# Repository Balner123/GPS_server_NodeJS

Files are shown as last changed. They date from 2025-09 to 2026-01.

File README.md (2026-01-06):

## LOTR - Location Tracker system

Dokumentace (PDF): [Dokumentace_LOTR_system](https://github.com/Balner123/GPS_server_NodeJS/blob/main/docs%26LaTex/FINAL_latex/Balner_LOTR_system.pdf)

Demo Serveru (Oracle cloud): [lotr-system.xyz](https://lotr-system.xyz)

Demo Prezentačního videa : [lotrsystem2026](https://www.youtube.com/@Lotrsystem)

## Popis a cíl projektu (deprecated)

Projekt LOTR (Location Tracker) je systém pro GPS sledování, který zahrnuje vlastní hardware, backendový server s webovým rozhraním, a APK pro Android (možná i jiné OS). 

### Klíčové Funkce (deprecated)

*   **Hardware:** Nízkoenergetické zařízení postavené na desce LilyGO T-Call (ESP32 + A7670E SIM modul), které v periodických intervalech zjišťuje polohu a odesílá ji na server dle konfigurace.
*   **Server:** Backend v Node.js (Express), který přijímá data, ukládá je do MySQL databáze a poskytuje API pro webové rozhraní.
*   **Webové rozhraní:** Umožňuje vizualizaci aktuální i historické polohy zařízení na mapě a konfiguraci jeho chování. nastavení dohledu (omezení plochy s výstrahou poopupuštění etc.), uživatelské učty + administrativní vhled do DB
*   **Aplikace** funkce stejného rázu jako HW zařízení + funkce "Dohledu" , "zamknutí" + "runaway report"

### Funkce HW

*   **registrace zařízení:** v servisním (OTA) režimu pomocí WiFi a webového serveru běžícího přímo na zařízení se uživatel přihlásí k registrovánému účtu a tím se bezpečně spáruje.
*   **odesílání dat:** Zařízení podporuje více režimů odesílání, které lze konfigurovat:
    1.  **Simple Mode:** Zjištění polohy a okamžité odeslání.
    2.  **Batch Mode:** Zařízení nejprve nasbírá určený počet poloh do interní paměti (cachování) a poté je odešle najednou v dávce. Tento režim výrazně šetří baterii snížením počtu síťových připojení.
*   **Odolnost vůči výpadkům:** Díky cachování zařízení neztratí data, pokud dočasně ztratí připojení k síti. Všechny nasbírané body odešle, jakmile je připojení opět dostupné.
*   **další funkce budou přidáné průběžně**

## Technologie a Hardware

### Software
Node.JS -> vybrán pro asynchronost a znalost
  + express -> minimalistiký
  + jakékoliv moduly
Možnost jakýchkoliv frontend frameworků

### Hardware

[lilygo t-call v1.0 A7670E](https://github.com/Balner123/GPS_server_NodeJS/blob/LilyGO-T-A76XX-main/MAIN/gps_tracker.ino)

[Multi-GNSS polohovací modul – L76K – GPS, BeiDou (BDS), GLONASS, QZSS – Waveshare 23721](https://botland.cz/gps-moduly/22732-multi-gnss-polohovaci-modul-l76k-gps-beidou-bds-glonass-qzss-waveshare-23721.html)

[Li-ion cell charger TP4056 with microUSB protection and STEP-UP booster ](https://www.laskakit.cz/nabijecka-li-ion-clanku-tp4056-boost-mt3608/)

[GeB Li-Ion Battery 1x18650 1S1P 3.7V 3200mAh  | LaskaKit](https://www.laskakit.cz/en/geb-li-ion-baterie-1x18650-1s1p-3-7v-3200mah/)

+ knihovny 

## Postup a vývoj+ milníky (deprecated)

- definování cílů -> základem byl fyzický Tracker -> server minimáně
- přechod na t-cal v1.4  místo v1.0 (lepší SIM modul + zkratování původní desky)
- větší zaměření na serverovou část

- více v "Poznámky k vývoji projektu.pdf" (neaktualizované z data 20.8)
- PLANY.txt
- a jakekoliv readme v podadresářích součástí projektu (analyzy dělané LLM - hlavně gemini)
- zbylá dokumentace je vedená v "Obsidian" bude exportována průběžně

## Další součásti (deprecated)
APK -> pro android a její vyvěšení na Google play (?) --> fee 20 dollars --> discontinued
3D tisknutá schránka pro hardwerovou část (?) --> stability issues --> ?

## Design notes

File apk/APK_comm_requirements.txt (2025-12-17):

===================================
APK Communication Requirements
===================================

1) Identita a autentizace
-------------------------
- APK klient používá uživatelský účet. Přihlášení probíhá přes `POST /api/apk/login` s JSON payloadem:
  {
    "identifier": "username nebo email",
    "password": "Secret123!",
    "installationId": "apk-install-uuid-12345"
  }
- Při úspěchu server založí HTTP session (`connect.sid` cookie) a vrací:
  {
    "success": true,
    "device_is_registered": false
  }
- Pokud účet není ověřen, server vrátí `403` a hlášku `Account not verified...`.
- Chybějící pole ⇒ `400`, špatné přihlašovací údaje ⇒ `401`, neexistující uživatel ⇒ `401`.
- Logout provádí `POST /api/apk/logout` (session zanikne, cookie se smaže).

2) Registrace zařízení / instalace APK
--------------------------------------
- Každá instalace APK vystupuje jako zařízení s `device_id = installationId` a `device_type = APK`.
- Varianty registrace:
  a) Legacy endpoint `POST /api/apk/register-device` (vyžaduje aktivní session z kroku 1).
     Payload:
     {
       "installationId": "apk-install-uuid-12345",
       "deviceName": "Pixel 8 Pro"
     }
     Odezvy: `201` vytvořeno, `200` již registrováno, `409` konflikt (patří jinému uživateli), `401` bez session, `400` chybějící pole.
  b) Unified endpoint `POST /api/devices/register`:
     {
       "client_type": "APK",
       "device_id": "apk-install-uuid-12345",
       "name": "Pixel 8 Pro"
     }
     Vyžaduje platnou session. Stejné návratové kódy jako výše.
- Server ukládá zařízení do `devices` a přidělí jej aktuálně přihlášenému uživateli.

3) Handshake (konfigurace + instrukce)
--------------------------------------
- Endpoint: `POST /api/devices/handshake`.
- Request (odesílat po startu aplikace a periodicky):
  {
    "client_type": "APK",
    "device_id": "apk-install-uuid-12345",
    "power_status": "ON",
  }
- Server kroky:
  • Pokud zařízení není registrováno ⇒ `registered=false` (HTTP 200). Aplikace má zařízení znovu zaregistrovat a pozastavit upload dat.
  • Aktualizuje `device_type`, `power_status`, `last_seen`. Pokud `power_status` potvrzuje předchozí instrukci, nastaví `power_instruction='NONE'`.
- Response při registrovaném zařízení:
  {
    "registered": true,
    "config": {
      "interval_gps": 15,
      "interval_send": 1,
      "satellites": 7,
      "mode": "batch"
    },
    "power_instruction": "NONE" | "TURN_OFF"
  }
- Aplikace musí respektovat dodanou konfiguraci a připravit se na instrukce vypnutí.

4) Odesílání telemetrie + potvrzení
-----------------------------------
- Endpoint: `POST /api/devices/input` (sdílený s HW). Middleware `authenticateDevice` ověřuje `device`/`device_id` proti DB – session není nutná, klíčem je registrované zařízení.
- Payload může být jeden objekt nebo pole objektů; každý bod musí mít `device`, `latitude`, `longitude`:
  {
    "device": "apk-install-uuid-12345",
    "client_type": "APK",
    "latitude": 50.12345,
    "longitude": 14.45678,
    "speed": 36.2,
    "accuracy": 5.1,
    "satellites": 12,
    "timestamp": "2025-12-01T10:15:00Z",
    "power_status": "OFF"   // pokud došlo k vypnutí po instrukci
  }
- Batch varianta:
  [ { ... }, { ... } ] – server uloží všechny body atomicky; prázdné pole ⇒ `400`.
- Po uložení server zaktualizuje `last_seen`, případně převezme nový `power_status`. Pokud status splní instrukci `TURN_OFF`, instruktáž se v DB vynuluje.
- Úspěšná odpověď: `{ "success": true }` (`200`).
- Chyby:
  • `400` – chybí `device`, `latitude`, `longitude` nebo některý bod je nekorektní.
  • `404` – `device` není registrováno.
  • `500` – interní chyba (klient opakuje s backoffem, nemazat uložená data).

5) Power status & instrukce
---------------------------
- `power_status`: `ON` | `OFF` (lze rozšířit o `LOW_POWER`, `FAULT`, ale APK aktuálně posílá pouze ON/OFF).
- `power_instruction`: `NONE` | `TURN_OFF` (nastavuje uživatel z UI přes `/api/devices/power-instruction`).
- Acknowledgement probíhá implicitně:
  • APK při dalším handshake nebo uploadu odešle `"power_status":"OFF"`.
  • Server při shodě `power_instruction=TURN_OFF` a `power_status=OFF` instrukci zruší.
- Aplikace musí zachovat konzistenci stavu: pokud obdrží `TURN_OFF`, přejde do OFF režimu, lokálně uloží data a potvrdí stav při nejbližším requestu.

6) Chování při chybách
----------------------
- `POST /api/apk/login`: 400 (missing fields), 401 (invalid credentials/user not found), 403 (account not verified), 500 (internal).
- `POST /api/devices/register`: 200/201 success, 400 invalid payload, 401 missing session, 409 conflict, 500 internal.
- `POST /api/devices/handshake`: 200 + `registered=false` (není registrováno), 500 internal error.
- `POST /api/devices/input`: 200 success, 400 invalid payload, 404 device unknown, 500 internal error.
- Po obdržení 401/403 musí APK uživatele znovu přihlásit (session je neplatná) a požadavek neopakovat se stejnou cookie.
- Při 409 (konflikt zařízení) je nutné uživateli nabídnout volbu změnit účet nebo zařízení přeregistrovat ručně.

7) Síťové požadavky & retry logika
----------------------------------
- Komunikace probíhá výhradně přes HTTPS. Session cookie `connect.sid` musí být bezpečně uložena (HttpOnly, Secure) a přikládaná k routám, které vyžadují autentizaci uživatele (`/api/apk/*`, `/api/devices/register`).
- Doporučený timeout požadavků < 10 s. Při selhání používat exponenciální backoff (start 5 s, max 60 s) a zachovat lokální buffer poloh.
- Telemetrii cacheovat offline; frontu odeslat v původním pořadí, protože server ukládá timestampy tak, jak dorazí.
- Po změně `installationId` (např. reinstall) je nutné znovu projít kroky 1–4.

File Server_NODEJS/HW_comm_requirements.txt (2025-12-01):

===================================
HW Communication Requirements
===================================

1) Identita a autentizace
-------------------------
- Každé HW zařízení používá pevné `device_id` (např. výrobní číslo).
- Registrace přes `POST /api/devices/register` s payloadem:
  {
    "client_type": "HW",
    "device_id": "ABC1234567",
    "username": "owner",
    "password": "secret",
    "name": "optional alias"
  }
- Server ověří uživatelské přihlašovací údaje a při úspěchu přiřadí zařízení k účtu.
- V případě konfliktní registrace (jiný uživatel) odpovědět 409.

2) Handshake (status + konfigurace)
-----------------------------------
- Endpoint: `POST /api/devices/handshake`.
- Příklad requestu:
  {
    "device_id": "ABC1234567",
    "client_type": "HW",
    "power_status": "ON",
  }
- Server provede:
  • Kontrolu registrace (`registered=false` v payloadu, status 200, pokud zařízení neexistuje).
  • Synchronizaci `power_status`, pokud na serveru není aktivní instrukce.
  • Vytvoření odpovědi s konfigurací a případnou instrukcí.
- Příklad response:
  {
    "registered": true,

    # if registered true : 

    "config": {
      "interval_gps": 60,
      "interval_send": 3,
      "satellites": 7,
      "mode": "batch",
    },
    "power_instruction": "TURN_OFF" | "NONE"
  }

3) Odesílání dat + ACK
----------------------
- Endpoint: `POST /api/devices/input` (stejný jako APK).
- Payload (jedna dávka):
  {
    "device": "ABC1234567",
    "latitude": 50.12345,
    "longitude": 14.45678,
    "speed": 35.6,
    "satellites": 8,
    "timestamp": "2025-11-07T10:20:00Z",
    "power_status": "OFF", # pokud se změnil po instrukci
  }
- Payload může být i pole výše uvedených objektů.
- Server kroky po přijetí:
  • Ověří `device` existenci.
  • Uloží lokace, aktualizuje `last_seen`.
  • Pokud `power_status` změněn na `OFF`, persistovat do `Device.power_status`.
  * pokud `power_status` sedí na aktuální instrukci, nulovat `power_instruction`.
  • Odpověď:
    {
      "success": true
    }

4) Power status a instrukce
---------------------------
- Enum hodnoty:
  • `power_status`: `ON`, `OFF`.
  • `power_instruction`: `NONE`, `TURN_OFF`.

5) Chování při chybách
----------------------
- 404 / `registered=false`: zařízením neprovádět další akce, přepnout do konfiguračního režimu.
- 409: stejné `device_id` už patří jinému uživateli. neprovádět další akce.
- 500: retry logika s backoffem; neztrácet data (uživatelské lokace).

7) Síťové požadavky
-------------------
- Všechny requesty přes HTTPS.
- Timeout doporučen < 10 s; při neúspěchu retry po 30 s.
- Podpora batch uploadu (pole) pro offline buffering.

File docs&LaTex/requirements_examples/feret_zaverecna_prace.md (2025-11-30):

Zde je kompletnì zpracovaný dokument do formátu **Markdown**. Zachoval jsem strukturu, formátování nadpisù, zvýraznìní kódu (C++/Arduino) a tabulky.

***

# ZÁVÌREÈNÁ STUDIJNÍ PRÁCE
## Dokumentace: Bezpeènostní systém se vzdáleným ovládáním

**Škola:** SŠPU Opava (Støední škola prùmyslová a umìlecká, Opava)  
**Autor:** Jakub Feret  
**Obor:** 18-20-M/01 INFORMAÈNÍ TECHNOLOGIE se zamìøením na poèítaèové sítì a programování  
**Tøída:** IT4  
**Školní rok:** 2017/2018

---

### Podìkování
Dìkuji panu uèiteli Ing. Petru Grussmannovi za cenné rady, panu uèiteli Mgr. Marcelu Godovskému za pomoc se souèástkami a panu uèiteli Mgr. Markovi Luènému za rady a pomoc pøi nahrání aplikace na školní hosting.

### Prohlášení
Prohlašuji, že jsem závìreènou práci vypracoval samostatnì a uvedl veškeré použité informaèní zdroje.

Souhlasím, aby tato studijní práce byla použita k výukovým úèelùm na Støední prùmyslové a umìlecké škole v Opavì, Praskova 399/8.

**V Opavì 31. 12. 2017**  
*(podpis autora práce)*

---

## ANOTACE

Projekt se zabývá tvorbou bezpeènostního systému s možností bezdrátového ovládání pøes WiFi. Skládá se z hardwarové a softwarové èásti. Základ hardwarové èásti tvoøí hlavnì vývojová deska NodeMcu. Zaøízení pomocí ultrazvukového senzoru snímá vzdálenost k nejbližší pøekážce, a pokud se tato vzdálenost zmìní, spustí se program. Ten po uplynutí aktivaèní doby upozorní uživatele SMS zprávou na možné narušení bezpeènosti. Zaøízení lze aktivovat i deaktivovat zadáním hesla z klávesnice, popøípadì pomocí webové aplikace. Programová èást bezpeènostního systému je øešena v jazyce Arduino, což je kombinace jazykù C a C++. Druhou èást projektu tvoøí webová aplikace vyvinutá v jazyce PHP s využitím Nette Frameworku. Tato aplikace umožòuje po pøihlášení vzdálenì ovládat bezpeènostní zaøízení. Administrátor mùže kromì aktivace nebo deaktivace alarmu také upravovat èasové prodlevy pøed aktivací nebo spravovat uživatelské úèty.

**Klíèová slova:** Bezpeènost; NodeMcu; ESP8266; Nette; WiFi; bezdrátová komunikace; webová aplikace; Arduino; PHP

---

## OBSAH

1. **VÝROBA BEZPEÈNOSTNÍHO SYSTÉMU**
2. **PRINCIP FUNGOVÁNÍ VZDÁLENÉHO OVLÁDÁNÍ**
3. **VYUŽITÉ TECHNOLOGIE**
    *   3.1 Hardware
        *   3.1.1 Seznam souèástek
        *   3.1.2 NodeMcu
        *   3.1.3 Ultrazvukový senzor HC-SR04
        *   3.1.4 LCD displej 1602
        *   3.1.5 Membránová klávesnice 4x4
        *   3.1.6 Bzuèák a LED
    *   3.2 Napájení
    *   3.3 Software
        *   3.3.1 Jazyk Arduino
        *   3.3.2 Webová aplikace
        *   3.3.3 Arduino IDE 1.8.5
        *   3.3.4 NetBeans 8.2
        *   3.3.5 XAMPP 5.6.32
        *   3.3.6 Fritzing 0.9.3b
4. **ZPÙSOBY ØEŠENÍ A POUŽITÉ POSTUPY**
    *   4.1 Hardwarové zaøízení
        *   4.1.1 Nahrávání programu
        *   4.1.2 Popis fungování bezpeènostního systému
        *   4.1.3 Ovìøení hesla
        *   4.1.4 Zmìna hesla
        *   4.1.5 Pøipojení k WiFi
        *   4.1.6 Komunikace se serverem
    *   4.2 Webová aplikace
        *   4.2.1 Pøihlášení
        *   4.2.2 Nastavení
        *   4.2.3 Bezdrátová komunikace
5. **VÝSLEDKY ØEŠENÍ**
    *   5.1 Podoba hardwarového zaøízení
    *   5.2 Podoba webové aplikace
    *   5.3 Bezdrátová komunikace
*   **ZÁVÌR**
*   **SEZNAM POUŽITÝCH INFORMAÈNÍCH ZDROJÙ**
*   **SEZNAM PØÍLOH**

---

## ÚVOD

Rozhodl jsem se vytvoøit bezpeènostní systém se vzdáleným ovládáním prostøednictvím webové aplikace, protože mi problematika Internetu vìcí, tedy propojení hardwarových zaøízení s Internetem, pøipadala velmi zajímavá a sám jsem si chtìl nìco takového vyzkoušet. Na podobném principu jako mùj bezpeènostní systém totiž mùže fungovat napøíklad ovládání celých chytrých domácností, kde je možné tøeba z mobilního telefonu zapnout svìtla, nebo postavit na èaj. Bezpeènostní systém upozorní uživatele SMS zprávou, svìtelným a zvukovým signálem na pohyb pøed senzorem. Zaøízení lze využít ke kontrole nemovitostí èi osobních pøedmìtù.

Hlavním cílem projektu však bylo propojit zaøízení se zabezpeèenou webovou aplikací a umožnit tím jeho vzdálené ovládání. Uživatel se k aplikaci pøipojí pomocí uživatelského jména a hesla. Bìžní uživatelé pak mohou systém bezpeènì aktivovat nebo deaktivovat. Administrátor má navíc možnost zmìnit v aplikaci dobu do aktivace a do spuštìní alarmu. Zároveò mùže vytváøet nové uživatelské úèty, popøípadì upravovat nebo mazat souèasné.

Protože se jednalo o mùj první projekt v této oblasti, zvolil jsem pro jeho realizace známé a dobøe zdokumentované technologie. S nìkterými z nich, jako napøíklad s Nette Frameworkem, jsem se již setkal ve škole. Hardwarovou èást tvoøí hlavnì vývojová deska NodeMcu s WiFi modulem ESP8266 a k nìmu pøipojené další komponenty, o kterých se ještì zmíním v dalších èástech dokumentace. Bezpeènostní zaøízení je naprogramováno v jazyce Arduino, jedná se o kombinaci jazykù C a C++. Webovou aplikaci øeším pomocí PHP frameworku Nette. Komunikace mezi aplikací a bezpeènostním zaøízením probíhá pøes WiFi na principu REST API.

V této dokumentaci podrobnì popisuji výrobu bezpeènostního systému a princip jeho fungování. Na zaèátku se zmiòuji o problémech, se kterými jsem se setkal pøi vývoji bezpeènostního zaøízení, pokraèuji popisem technologií nezbytných k jeho výrobì i k jeho souèasné funkènosti a rozebírám, jak funguje nejen samotné bezpeènostní zaøízení, ale i webová aplikace potøebná k jeho vzdálenému ovládání. V další èásti vysvìtluji, na jakých principech funguje jejich vzájemná komunikace, a popisuji jednotlivé úkony obou èástí systému. V závìru se zabývám souèasnou podobou bezpeènostního systému a hodnotím odvedenou práci.

---

# 1 VÝROBA BEZPEÈNOSTNÍHO SYSTÉMU

První èást mého projektu pøedstavovalo sestavení samotného zaøízení. Protože se jednalo o mou první zkušenost se sestavováním integrovaných obvodù, výbìru a nákupu souèástek pøedcházel zdlouhavý výzkum dané problematiky. Nejdøíve jsem se rozhodl jako základ mého zaøízení použít vývojovou desku Arduino UNO, založenou na mikrokontroléru ATmega328 od firmy Atmel. Pro komunikaci s webovou aplikací jsem vybral WiFi modul ESP8266-01. Toto spojení se však èasem ukázalo jako nepraktické a neefektivní, proto jsem se rozhodl nahradit jak Arduino UNO, tak ESP8266-01 vývojovou deskou NodeMcu, která již obsahuje WiFi modul ESP8266.

Vzhledem k tomu, že jsem s nakoupenými souèástkami nikdy døíve nepracoval, rozhodl jsem se postupovat po malých krocích. Zapojoval jsem jednu souèástku po druhé do nepájivého pole a hned jsem zkoušel její funkènost pomocí jednoduchých pøíkladù v Arduino IDE. Finální verzi projektu jsem nejdøíve navrhl v programu Fritzing, kde jsem si odzkoušel rozvržení souèástek na nepájivém poli.

Po zapojení a odzkoušení všech souèástek jsem pøešel k programování samotného bezpeènostního systému. Pro tento úèel jsem zvolil programovací jazyk pøímo pro Arduino, což je kombinace jazykù C a C++. Když byla první èást projektu plnì funkèní, èekala mì ta pravá výzva – spojit zaøízení pøes WiFi s webovou aplikací a umožnit tak jeho ovládání na dálku, což byl, jak jsem již zmiòoval, hlavní cíl mého projektu.

Webovou aplikaci jsem se rozhodl vyøešit pomocí PHP frameworku Nette, se kterým jsem již mìl zkušenost ze školy, spolu s databázovým systémem MySQL. Protože se jedná o aplikaci urèenou pro ovládání bezpeènostního systému, snažil jsem se ji co nejvíce zabezpeèit. Každý uživatel aplikace se musí nejprve pøihlásit svým uživatelským jménem a heslem. Administrátor pak mùže vytváøet, upravovat èi mazat uživatele a má také plnou kontrolu nad samotným bezpeènostním zaøízením – mùže mìnit intervaly pøed aktivací a pøed spuštìním alarmu a samozøejmì také zaøízení na dálku zapnout nebo vypnout. Ostatní uživatelé pak mají možnost zmìnit pouze vlastní pøihlašovací údaje a také mohou zapnout nebo vypnout alarm.

---

# 2 PRINCIP FUNGOVÁNÍ VZDÁLENÉHO OVLÁDÁNÍ

Propojení ESP8266 a webové aplikace jsem nejdøíve øešil tak, že jsem v aplikaci mìnil hodnoty v MySQL databázi a k nim jsem pak pøistupoval z ESP8266 pomocí knihovny MySQL Connector. To se ukázalo jako nevyhovující, jednak kvùli bezpeènosti a také kvùli tomu, že by toto øešení spolehlivì fungovalo pouze na lokální úrovni.

Rozhodl jsem se radìji vytvoøit jednoduché REST API. V aplikaci vypisuji hodnoty do JSON výstupu a k tomu pøistupuji z ESP8266 pomocí HTTP GET požadavku. Pøijatá data pak pomocí knihovny ArduinoJson dekóduji a ukládám do promìnných, se kterými pak mùžu dále pracovat. Díky tomu jsem schopen alarm na dálku zapnout, popøípadì zmìnit jeho nastavení. Bylo však také potøeba zajistit, aby se server dozvìdìl o pøípadném manuálním vypnutí alarmu z klávesnice a zmìnil pak pøíslušnou hodnotu v databázi. Tento problém jsem vyøešil pomocí požadavku POST. Opìt vytváøím JSON výstup, tentokrát ho však posílám do Nette webové aplikace, kde ho dekóduji a ukládám do databáze. Ani tento postup však není pøíliš vhodný, zejména kvùli potøebì posílat v pravidelných intervalech požadavky na server (napøíklad každých deset vteøin, nejlépe ještì èastìji) a zjiš�ovat, zda se hodnoty nezmìnily. To vede k velkému odbìru elektrické energie, což mi znemožòuje napájet zaøízení z baterie, jak jsem pùvodnì plánoval.

To by bylo možné, pokud bych zaøízení propojil se serverem bez nutnosti posílat na nìj každou chvíli požadavky. Mohl bych tak uvést zaøízení do režimu spánku, dokud by nedostalo impuls k probuzení, napøíklad zmìnìním urèité hodnoty. Tím bych výraznì snížil spotøebu elektrické energie. Chtìl jsem proto opìt zmìnit princip komunikace mezi webovou aplikací a ESP8266, konkrétnì jsem mìl v plánu použít komunikaèní protokol MQTT, který umožòuje propojení se serverem bez nutnosti neustálého posílání požadavkù. Protože však Nette MQTT nijak nepodporuje, bylo by nutné kompletnì pøepsat webovou aplikaci, nejlépe do jiného jazyka (napøíklad Pythonu), což by se mi bohužel nepodaøilo stihnout pøed termínem odevzdání projektu, a tak jsem zaøízení ponechal v souèasném funkèním, avšak ne zcela vyhovujícím stavu.

---

# 3 VYUŽITÉ TECHNOLOGIE

## 3.1 Hardware

### 3.1.1 Seznam souèástek
*   Vývojová deska NodeMcu,
*   ultrazvukový senzor HC-SR04,
*   LCD displej 1602,
*   LCD I2C sériové rozhraní
*   membránová klávesnice 4x4,
*   I2C sbìrnice PCF8574P,
*   5 V bzuèák,
*   èervená LED,
*   rezistor 330 ?,
*   obousmìrný osmi-kanálový pøevodník logických úrovní,
*   napájecí modul nepájivého pole,
*   2 nepájivé pole se 400 kontakty.

### 3.1.2 NodeMcu
Základ projektu tvoøí vývojová deska NodeMcu (obrázek è. 1). Firmware obstarává WiFi modul ESP8266 od spoleènosti Espressif Systems, hardware je založen na modulu ESP-12E, ovšem s šesti GPIO piny navíc. NodeMcu tedy obsahuje 12 digitálních GPIO pinù a jeden analogový pin (obrázek è. 2). Pro program je k dispozici pamì� o velikosti 128 kB. Na rozdíl od vìtšiny ostatních komponentù, NodeMcu pracuje s napìtím 3,3 V.
*Obrázek è. 1 NodeMcu | Obrázek è. 2 Piny NodeMcu*

### 3.1.3 Ultrazvukový senzor HC-SR04
Bezpeènostní systém funguje na principu ultrazvukových vln, které mìøí vzdálenost k nejbližší pøekážce. To zajiš�uje ultrazvukový senzor HC-SR04, který je schopný pomocí ultrazvukových vln zmìøit vzdálenost od dvou do 400 cm s pøesností plus mínus tøi milimetry. Úhel mìøení je 15 stupòù. Senzor po aktivaci automaticky pošle osm 40 kHz vln a èeká na odražený signál. Pokud odražený signál dorazí zpìt, senzor zaznamená èas od vyslání vlny k jejímu návratu. Vzdálenost se pak vypoèítá jako `doba od vyslání vlny k jejímu návratu * rychlost zvuku / 2` (obrázek è. 3). Pøi vymýšlení principu fungování bezpeènostního zaøízení jsem se rozhodoval mezi ultrazvukovým senzorem a pohybovým èidlem. Pro ultrazvukový senzor jsem se rozhodl hlavnì proto, že pohybové èidlo po spuštìní snímá celou místnost a zaznamená jakýkoliv pohyb v dané místnosti. Nehodí se proto do domácností s volnì se pohybujícími zvíøaty. Ultrazvukový senzor naproti tomu snímá pouze urèitou oblast pøímo pøed sebou, takže pokud se nainstaluje na správné místo, je senzor schopen zaznamenat napøíklad otevøení dveøí, avšak zvíøe procházející kolem dveøí už nezaznamená.

```cpp
// Custom function for the Ultrasonic sensor
long getDistance() {
  // Clears the trigPin
  digitalWrite(trigPin, LOW);
  delayMicroseconds(2);
  // Sets the trigPin on HIGH state for 10 micro seconds
  digitalWrite(trigPin, HIGH);
  delayMicroseconds(10);
  digitalWrite(trigPin, LOW);
  // Reads the echoPin, returns the sound wave travel time in microseconds
  duration = pulseIn(echoPin, HIGH);
  // Calculating the distance
  distance = duration * 0.034 / 2;
  return distance;
}
```
*Obrázek è. 3 Funkce pro získání vzdálenosti z ultrazvukového senzoru*

### 3.1.4 LCD displej 1602
Jako výstupní zaøízení jsem použil LCD displej 1602, který dokáže zobrazit 32 znakù na dvou øádcích (16 x 2). Kvùli omezenému poètu pinù na NodeMcu jsem pro pøipojení využil I2C sériové rozhraní, které mi umožnilo pøipojit displej pouze dvìma vodièi. Funkènost displeje obstarává knihovna `LiquidCrystal_I2C`.

### 3.1.5 Membránová klávesnice 4x4
Uživatelský vstup øeším pomocí membránové klávesnice o šestnácti klávesách (4 øádky a 4 sloupce). Pro fungování klávesnice je potøeba osm vodièù, pro které jsem však nemìl k dispozici dostatek pinù. Nejdøíve jsem se proto rozhodl zredukovat osm digitálních pinù na jeden analogový, a to pomocí pole rezistorù. Využil jsem toho, že funkce `analogRead()` dokáže pøiøadit vstupní napìtí od 0 do 3,3 V èíselným hodnotám od 0 do 1024. Díky rezistorovému poli bude po zmáèknutí každé klávesy tato hodnota vždy jiná. Napsal jsem si tedy jednoduchou knihovnu v jazyce C++, která ke každé hodnotì, kterou získám funkcí `analogRead()` z analogového pinu, pøiøadí danou klávesu. Bohužel po pøechodu z Arduino Uno na NodeMcu toto øešení vyústilo v øadu problémù, zejména kvùli nedokonalému vyvedení analogového pinu NodeMcu, na kterém jsem namìøil èetné výkyvy signálu zpùsobující nepøedvídatelné chování kláves. Rozhodl jsem se proto vyøešit zapojení klávesnice pomocí I2C sbìrnice PCF8574P, podobnì jako u LCD displeje.

Protože je díky I2C sbìrnici klávesnice pøipojená ke stejným pinùm jako LCD displej, zbývá mi dostatek pinù pro ostatní komponenty. Aby to však bylo možné, nesmí mít LCD displej a klávesnice stejnou I2C adresu. Pomocí jednoduchého Arduino programu jsem zjistil, že displej používá adresu 0x27, staèilo tak nastavit pro klávesnici jakoukoliv jinou adresu, s èímž mi pomohla tabulka na obrázku è. 4. Zvolil jsem adresu 0x21, takže bylo nutné u I2C sbìrnice PCF8574P uzemnit piny A2 a A1 a pin A0 pøipojit k napìtí 3,3 V.

**ADDRESS REFERENCE**

| INPUTS | | | I2C-BUS SLAVE ADDRESS |
| :---: | :---: | :---: | :--- |
| **A2** | **A1** | **A0** | |
| L | L | L | 32 (decimal), 20 (hexadecimal) |
| L | L | H | 33 (decimal), 21 (hexadecimal) |
| L | H | L | 34 (decimal), 22 (hexadecimal) |
| L | H | H | 35 (decimal), 23 (hexadecimal) |
| H | L | L | 36 (decimal), 24 (hexadecimal) |
| H | L | H | 37 (decimal), 25 (hexadecimal) |
| H | H | L | 38 (decimal), 26 (hexadecimal) |
| H | H | H | 39 (decimal), 27 (hexadecimal) |

*Obrázek è. 4 Tabulka pro urèení I2C adresy*

Funkènost klávesnice obstarává knihovna `Keypad_I2C`. Hodnoty kláves se zapisují do dvourozmìrného pole (obrázek è. 5).

```cpp
char keypressed;
const byte ROWS = 4;
const byte COLS = 4;
char hexaKeys[ROWS][COLS] = {
  {'1', '2', '3', 'A'},
  {'4', '5', '6', 'B'},
  {'7', '8', '9', 'C'},
  {'*', '0', '#', 'D'}
};
byte rowPins[ROWS] = {0, 1, 2, 3};
byte colPins[COLS] = {4, 5, 6, 7};
Keypad_I2C customKeypad(makeKeymap(hexaKeys), rowPins, colPins, ROWS, COLS, 0x21);
```
*Obrázek è. 5 Deklarace promìnných pro klávesnici*

Dále je potøeba klávesnici inicializovat ve funkci `setup()` (obrázek è. 6).
```cpp
// keypad inicialization
customKeypad.begin();
```
*Obrázek è. 6 Inicializace klávesnice*

Vždy, když je potøeba v nìjaké funkci zjiš�ovat, zda byla stisknuta nìjaká klávesa, musí se z knihovny Keypad_I2C zavolat funkce `getKey()` (obrázek è. 7).
```cpp
// get pressed key
keypressed = customKeypad.getKey();
```
*Obrázek è. 7 Zapsání stisknuté klávesy do promìnné keypressed*

### 3.1.6 Bzuèák a LED
Souèástí zaøízení je také 5 V bzuèák o frekvenci 2,3 kHz, který slouží k upozornìní na stisknutí tlaèítka a také jako bezpeènostní prvek, který má hlasitým zvukem vylekat pøípadného narušitele. Jako další bezpeènostní prvek slouží èervená LED, která po spuštìní alarmu zaène jasnì svítit.

## 3.2 Napájení
Problém nastal pøi øešení napájení jednotlivých komponentù, zejména proto, že vývojová deska NodeMcu a WiFi modul ESP8266 pracují s jiným napìtím, než ostatní souèástky. Konkrétnì NodeMcu vyžaduje napìtí 3,3 V, zatímco ostatní komponenty 5 V. Tento problém jsem se rozhodl vyøešit pomocí obousmìrného osmi-kanálového pøevodníku logických úrovní, který je schopen pøevádìt 5 V na 3,3 V a naopak.

Samotné napájení je øešeno pomocí napájecího modulu nepájivého pole, který dokáže pøipojit napájení do dvou napì�ových vìtví. U každé z nich lze jumperem zvolit, jaké napìtí do ní bude pøivedeno (buï 3,3 V, nebo 5 V). Modul vyžaduje vstupní napìtí od 6,5 V do 12 V, které lze pøivést kabelem z elektrické sítì nebo pomocí USB z poèítaèe. Maximální výstupní proud je 700 mA, což je dostaèující pro napájení vìtšiny souèástek.

Všechny komponenty jsem pøipojil na dvì nepájivá pole, každé z nich disponuje 400 kontakty.

## 3.3 Software
### 3.3.1 Jazyk Arduino
Program sloužící k ovládání hardwarových souèástek jsem napsal v jazyce Arduino, který je, až na drobné úpravy, velmi podobný jazyku C nebo C++. Jazyk Arduino byl pøímo vytvoøen k programování integrovaných obvodù.

### 3.3.2 Webová aplikace
Webovou aplikaci jsem øešil v jazyce PHP, konkrétnì jsem využil PHP frameworku Nette ve verzi 2.4. Pøi tvorbì uživatelského rozhraní jsem použil framework Bootstrap v3.3.4, který mi usnadnil práci s HTML5 a CSS, hlavnì v oblasti responzibility. Vzhled uživatelského rozhraní jsem øešil pomocí kaskádových stylù CSS3 a také pomocí javascriptové knihovny jQuery. K provozu aplikace využívám databázový systém MySQL, ve kterém ukládám jak uživatelské údaje, tak data nutná pro ovládání samotného bezpeènostního zaøízení. Celá aplikace bìží na Apache HTTP Serveru.

### 3.3.3 Arduino IDE 1.8.5
Jako vývojové prostøedí jsem pro Arduino program zvolil Arduino IDE 1.8.5, které je pøímo uzpùsobeno pro nahrávání programù do vývojových desek jako Arduino nebo NodeMcu.

### 3.3.4 NetBeans 8.2
Pro vývoj PHP webové aplikace jsem zvolil integrované vývojové prostøedí NetBeans 8.2, kvùli jeho pøehlednému uživatelskému rozhraní a jeho podpoøe množství programovacích jazykù.

### 3.3.5 XAMPP 5.6.32
Pøi vývoji webové aplikace byl nezbytný multiplatformní softwarový balíèek XAMPP, díky kterému je možné vytvoøit lokální webový server. Konkrétnì jsem použil verzi 5.6.32. Balíèek obsahuje serverovou aplikaci Apache, databázi MariaDB a skriptovací jazyk PHP. XAMPP jsem zvolil kromì jeho jednoduchosti a intuitivního ovládání také proto, že vìtšina webových serverù využívá stejné komponenty jako XAMPP, takže je pøechod z lokálního testovacího serveru na živý server velmi jednoduchý.

### 3.3.6 Fritzing 0.9.3b
Pro návrh bezpeènostního zaøízení jsem použil open-source program Fritzing ve verzi 0.9.3b. Ten umožòuje graficky sestavit zapojení jednotlivých souèástek na nepájivém poli, což pomáhá k lepší pøedstavì o výsledném rozložení. Program dále usnadòuje tvorbu schématu zaøízení, podle kterého lze pak navrhnout desku plošných spojù, jejíž výrobu je možné pøímo v programu objednat.

---

# 4 ZPÙSOBY ØEŠENÍ A POUŽITÉ POSTUPY

## 4.1 Hardwarové zaøízení
### 4.1.1 Nahrávání programu
Bezpeènostní zaøízení je umístìno v uzavøené krabièce, pøípadná úprava programu pøes sériový port je proto znaènì problematická a v bìžném provozu prakticky nemožná. Tento problém jsem vyøešil zprovoznìním OTA (over the air) pøenosu pomocí knihovny ArduinoOTA, která mi umožòuje nahrát firmware do ESP8266 bezdrátovì pøes WiFi. Po zapnutí zaøízení je vyèlenìn èas, ve kterém je možné bezdrátovì nahrát nový program (obrázek è. 8) a teprve po uplynutí tohoto èasu zaène bezpeènostní systém pracovat.

```cpp
//over the air transfer
if(ota == true) {
  //after the reboot, over the air transfer can be used for certain time
  while (otaTransfer < otaTime) {
    otaCurrent = millis();
    if (otaCurrent - otaPrevious >= otaInterval) {
      otaPrevious = otaCurrent;
      otaTransfer++;
    }
    ArduinoOTA.handle();
    yield();
  }
  //when over the air transfer ended, the ledBlink() function is called
  ledBlink();
  ota = false;
}
```
*Obrázek è. 8 Odpoèítávání èasu, ve kterém je možné bezdrátovì nahrát nový firmware*

### 4.1.2 Popis fungování bezpeènostního systému
Po zapnutí NodeMcu se automaticky spustí funkce `setup()`. Ta se pøipojí k WiFi pomocí knihovny WiFiManager a zavolá funkci `loop()`, která nejprve na nìkolik vteøin umožní bezdrátovì nahrát nový program pomocí OTA (over the air) pøenosu (obrázek è. 8), poté vypíše na displej zprávu a zavolá funkci `enterPassword()`. Po zadání správného hesla se spustí funkce `activateAlarm()`, která odpoèítává èas do aktivace systému. Tento èas slouží k opuštìní hlídaného prostoru. Uživatel má zároveò možnost odpoèet zrušit, a to stisknutím klávesy C a zadáním správného hesla, èímž se opìt zavolá funkce `loop()`. Po uplynutí èasu se spustí funkce `alarmCheck()` (obrázek è. 9), která pomocí funkce `getDistance()` aktivuje ultrazvukový senzor a zaène mìøit vzdálenost k nejbližší pøekážce.

```cpp
currentDistance = getDistance() + 30;
if (currentDistance < initialDistance) {
  danger = true;
  check = false;
  warning = warn;
  countdown = 0 - 1;
  while (warning != 0 - 1) {
    if (message == 0) {
      lcd.clear();
      lcd.setCursor(4, 0);
      lcd.print("WARNING");
      message = 1;
    }
    active = false;
    activateMessage = false;
    alarmMessage = false;
    cancelMessage = false;
    warningMessage = true;
    deactivate = true;
    enterPassword();
    yield();
  }
  alarmActivated();
}
```
*Obrázek è. 9 Ukázka kódu funkce alarmCheck()*

Pokud se tato vzdálenost zmìní, aktivuje se odpoèet do spuštìní alarmu, pomocí funkce `ledBlink()` se rozbliká LED a zavolá se funkce `enterPassword()`, což dává uživateli možnost zadat platné heslo a tím odpoèet zrušit. Pokud to neudìlá, zavolá se po uplynutí odpoètu funkce `alarmActivated()`. Ta spustí naplno bzuèák a jasnì rozsvítí èervenou LED. Zároveò se informace o spuštìní alarmu odešle na server a webová aplikace zajistí odeslání SMS uživateli. Nakonec se zavolá funkce `enterPassword()`, ve které lze zadáním správného hesla alarm deaktivovat.

### 4.1.3 Ovìøení hesla
Stìžejní funkcí programu je funkce `enterPassword()`. Pøi tvorbì zaøízení pro mì byla bezpeènost systému velmi dùležitá, proto musí být naprostá vìtšina požadavkù ovìøená zadáním hesla. Na zaèátku se zavolá funkce `eepromRead()`, která zpøístupní souèasné platné heslo uložené v EEPROM pamìti pro porovnání se zadaným heslem. Pak pøijde na øadu funkce `temporaryPassword()`, jejíž úkolem je èíst hodnotu stisknuté klávesy a ukládat ji do promìnné. Po stisknutí klávesy `*` se ve funkci `enterPassword()` tato promìnná porovná s platným heslem uloženým v EEPROM pamìti. Následující akce se odvíjejí od souèasné situace alarmu – pokud je alarm vypnutý a je zadáno platné heslo, spustí se funkce pro aktivaci alarmu `activateAlarm()`. Pokud je alarm již zapnutý a je zadáno platné heslo, zavolá se naopak funkce pro deaktivaci alarmu `deactivateAlarm()`. Uživatel má také možnost zrušit probíhající odpoèet do aktivace alarmu a i v tomto pøípadì funkce `enterPassword()` zajistí po zadání hesla deaktivaci alarmu. Pøi pokusu o deaktivaci alarmu pøed vypršením èasu do spuštìní má uživatel tøi pokusy na zadání platného hesla. Pokud se mu to nepodaøí, je okamžitì zavolána funkce `alarmActivated()` a alarm se spustí.

### 4.1.4 Zmìna hesla
Uživatel má také možnost souèasné heslo zmìnit, stará se o to funkce `changePassword()`. Funkci lze vyvolat, pokud alarm není aktivován, stisknutím klávesy B. Funkce vyžaduje zadání souèasného a nového hesla. Nové heslo musí mít ètyøi až šest èísel a kvùli zamezení pøípadným pøeklepùm je nutné ho zadat dvakrát. Pokud jsou všechny podmínky splnìny, zavolá se funkce `eepromWrite()`, která nové heslo uloží do EEPROM pamìti.

### 4.1.5 Pøipojení k WiFi
Pro snadnìjší pøipojení k WiFi jsem využil knihovnu WiFiManager pro ESP8266. Díky ní se zaøízení po zapnutí automaticky pokusí o pøipojení k již nakonfigurované WiFi síti. Pokud se to nepodaøí, nebo pokud ještì žádná sí� nakonfigurována nebyla, automaticky vytvoøí web server, na kterém uživatel zadá heslo ke své WiFi a ESP8266 se k ní pak bude automaticky pøipojovat.

### 4.1.6 Komunikace se serverem
Pro vzdálené ovládání bezpeènostního zaøízení je nutná jeho komunikace se serverem. Tu zajiš�uji pomocí HTTP GET a POST požadavkù z ESP8266 na server.

**Získávání hodnot**
Získávání dat ze serveru øeším pomocí HTTP GET požadavku z ESP8266. Funkce `getValues()` se pøipojí k serveru a získá HTML stránku, která obsahuje JSON s daty. Následnì se zbaví hlavièky stránky a pomocí knihovny ArduinoJson dekóduje JSON data. Ta se pak uloží do promìnných, se kterými lze dále pracovat (obrázek è. 10).

```cpp
//read response from the server
String section = "header";
while (client.available()) {
  String content = client.readStringUntil('\r');
  //Serial.print(content);
  //get rid of the header
  if (section == "header") {
    Serial.print(".");
    if (content.charAt(1) == '9') {
      section = "json";
    }
  }
  else if (section == "json") {
    Serial.println("");
    section = "ignore";
    String json = content;
    //parse JSON
    StaticJsonBuffer<200> jsonBuffer;
    JsonObject& json_parsed = jsonBuffer.parseObject(json);
    if (!json_parsed.success()) {
      Serial.println("Parsing failed!");
      return;
    }
    //save values into variables
    countdown = json_parsed["settings"]["countdown"];
    warning = json_parsed["settings"]["warning"];
    count = json_parsed["settings"]["countdown"];
    warn = json_parsed["settings"]["warning"];
    activate = (json_parsed["settings"]["activate"]).as<String>();
```
*Obrázek è. 10 Ukázka kódu z funkce pro získání JSON dat ze serveru*

**Odesílání hodnot**
Odesílání dat na server mi zajiš�uje funkce `postValues()`. Ta zakóduje data do JSON výstupu, pøipojí se na server a pomocí HTTP POST požadavku tato data odešle (obrázek è. 11). Zbytek obstará samotná webová aplikace.

```cpp
//create JSON
StaticJsonBuffer<200> jsonBuffer;
JsonObject& json_created = jsonBuffer.createObject();
json_created["activate"] = activate;
json_created["alarm"] = alarm;
char jsonMessageBuffer[200];
json_created.printTo(jsonMessageBuffer, sizeof(jsonMessageBuffer));
//send POST request to the server
client.println(String("POST ") + postPath+" HTTP/1.1");
client.println(String("Host: ") + host);
client.println("Connection: close");
client.println("Content-Type: application/json");
client.print("Content-Length: ");
client.println(strlen(jsonMessageBuffer));
client.println();
client.println(jsonMessageBuffer);
```
*Obrázek è. 11 Ukázka kódu z funkce pro odesílání JSON dat na server*

## 4.2 Webová aplikace
Pøi tvorbì webové aplikace mi znaènì usnadnil práci Nette Framework, který již obsahuje èetná bezpeènostní opatøení. Napøíklad pro pøihlašování uživatelù tedy využívám funkce, které již Nette v základu má. Pøi øešení designu aplikace mi pomohl framework Bootstrap, díky kterému je uživatelské rozhraní plnì responzivní. Dùležitou èástí aplikace je databázový systém MySQL, do kterého prostøednictvím Nette ukládám data, ke kterým pak mùžu pøistupovat.

### 4.2.1 Pøihlášení
Do aplikace je nejprve vždy nutné se pøihlásit pomocí uživatelského jména a hesla (obrázek è. 12).
*Obrázek è. 12 Pøihlašovací okno do webové aplikace*

Po pøihlášení se pomocí údajù v databázi rozhodne, zda se pøihlásil bìžný uživatel nebo administrátor. Na tom závisí, jaká práva bude daný uživatel v aplikaci mít.

### 4.2.2 Nastavení
Bìžný uživatel mùže upravit své osobní údaje jako jméno nebo heslo (obrázek è. 13) a také mùže aktivovat nebo deaktivovat alarm.
*Obrázek è. 13 Formuláø pro zmìnu hesla*

Administrátor mùže kromì již zmínìného také upravovat údaje ostatních uživatelù, popøípadì pøidávat nové uživatele nebo mazat souèasné (obrázek è. 14).
*Obrázek è. 14 Administrace uživatelù*

Má právo také upravovat dobu do aktivace a dobu do spuštìní alarmu (obrázek è. 15).
*Obrázek è. 15 Nastavení bezpeènostního zaøízení*

### 4.2.3 Bezdrátová komunikace
Dùležitým úkolem webové aplikace je také komunikace s hardwarovým zaøízením. Ta je øešena pomocí REST API. Za úèelem poskytování dat pro ESP8266 jsem vytvoøil funkci, která získá data z databáze a vytvoøí z nich JSON výstup. Ten si potom snadno stáhne a dekóduje samotné zaøízení pomocí HTTP GET požadavku. Získávání dat z ESP8266 jsem vyøešil pomocí HTTP POST požadavku ze zaøízení, ve kterém posílám JSON výstup. Tato data pak v aplikaci zpracuji, JSON dekóduji a hodnoty uložím do databáze.

---

# 5 VÝSLEDKY ØEŠENÍ

## 5.1 Podoba hardwarového zaøízení
Bezpeènostní zaøízení je v souèasné dobì plnì funkèní, po nìkolika denním testování splòuje mé poèáteèní oèekávání a všechny jeho funkce bez problému fungují. Z dùvodu èastých úprav je zaøízení umístìno na dvou nepájivých polích. Do budoucna by bylo vhodné vytvoøit pevný plošný spoj na poli pájivém, zejména kvùli køehkosti souèasného øešení. Systém jsem umístil do jednoduché krabièky s vyvrtanými otvory pro napájecí kabel a pro ultrazvukový senzor. Jak jsem již døíve v dokumentaci zmiòoval, napájení kabelem z elektrické sítì není u bezpeènostního systému vhodné, protože by pøípadnému narušiteli staèilo vytrhnout napájecí kabel z elektrické zásuvky. Lepší by bylo napájet zaøízení výkonnou baterií schovanou v krabièce, popøípadì systém umístit napevno do zdi a pøímo pøipojit k elektrické síti.
*Obrázek è. 16 Bezpeènostní zaøízení ve vývoji*

## 5.2 Podoba webové aplikace
Webová aplikace spolehlivì splòuje svùj úèel, uživatelé se bez problému pøihlásí a následnì mohou v aplikaci dìlat pøesnì to, co jim dovolují jejich uživatelská práva. Bìžní uživatelé se proto nedostanou k administrátorským nastavením nebo k jiným nepøístupným èástem aplikace. Administrátor naopak mùže kdykoliv mìnit všechny údaje: své vlastní, údaje ostatních uživatelù a samozøejmì nastavení bezpeènostního zaøízení. Aplikace je také plnì responzivní, lze ji proto používat i na mobilních telefonech nebo tabletech. Do budoucna bych rád pøidal více možností nastavení jako napøíklad automatickou aktivaci bezpeènostního systému v urèité dobì a podobnì.
*Obrázek è. 17 Tlaèítko pro deaktivaci alarmu | Obrázek è. 18 Tlaèítko pro aktivaci alarmu*

## 5.3 Bezdrátová komunikace
Komunikace mezi webovou aplikací a hardwarovým zaøízením na principu REST API funguje spolehlivì. Pro bezpeènostní zaøízení však není nejvhodnìjší, jak z hlediska bezpeènosti, tak samotné funkènosti, jelikož je nezbytné zasílat ze zaøízení požadavky na server v pravidelných èasových intervalech a mezi tìmito intervaly se zaøízení nemá jak dozvìdìt o pøípadných zmìnách v aplikaci (napøíklad o impulsu k aktivaci alarmu). Vhodnìjší by proto pro tento konkrétní pøípad bylo využití jiné technologie, napøíklad protokolu MQTT, který by zaøízení se serverem spojil trvale a reagoval by pouze na zmìny. Rád bych také komunikaci lépe zabezpeèil proti pøípadným pokusùm o narušení, napøíklad pomocí protokolu HTTPS.

---

# ZÁVÌR
Cílem projektu bylo vytvoøit funkèní bezpeènostní systém s možností ovládat jej na dálku prostøednictvím webové aplikace. Vytyèené cíle byly splnìny, bezpeènostní zaøízení i webová aplikace bez problému fungují. Pøi vývoji mì nicménì napadl nespoèet možných zmìn, které by zaøízení vylepšily, jako napøíklad napájení z baterie nebo lepší zpùsob komunikace mezi aplikací a zaøízením. Na tato vylepšení mi již bohužel nestaèil èas pøed termínem odevzdání práce, proto se jim budu vìnovat pozdìji. Rád bych také pøidal více možností nastavení do webové aplikace, jako napøíklad možnost automaticky aktivovat alarm v urèitou dobu a podobnì. Samotné souèástky bych rád umístil na desku plošných spojù místo dvou nepájivých polí, èímž bych vyøešil problém s køehkostí celého zaøízení.

---

# SEZNAM POUŽITÝCH INFORMAÈNÍCH ZDROJÙ

1.  ESP8266 Quick Start Guide [online]. [cit. 2017-12-28]. Dostupné z: http://rancidbacon.com/files/kiwicon8/ESP8266_WiFi_Module_Quick_Start_Guide_v_1.0.4.pdf
2.  Logic Level Shifting [online]. [cit. 2017-12-28]. Dostupné z: http://www.instructables.com/id/A-Quick-Guide-on-Logic-Level-Shifting/
3.  ESP8266 Full Communication From Anywhere in the World [online]. In: 12. 12. 2015 [cit. 2017-12-28]. Dostupné z: https://www.youtube.com/watch?v=uWbLpMJ8jiA
4.  Nette autentifikace [online]. [cit. 2017-12-28]. Dostupné z: https://doc.nette.org/cs/2.4/quickstart/authentication
5.  Nette autentizace [online]. [cit. 2017-12-28]. Dostupné z: https://doc.nette.org/cs/2.4/access-control
6.  Nette Tracy [online]. [cit. 2017-12-28]. Dostupné z: https://tracy.nette.org/cs/
7.  Drahak REST API, chránìná komunikace [online]. [cit. 2017-12-28]. Dostupné z: https://www.itnetwork.cz/php/nette/diskuzni-forum-php-nette-framework/drahak-rest-api-chranena-komunikace-5767f69a2b12b
8.  JSON decode [online]. [cit. 2017-12-28]. Dostupné z: http://php.net/manual/en/function.json-decode.php
9.  ArduinoJson [online]. [cit. 2017-12-28]. Dostupné z: https://github.com/bblanchon/ArduinoJson
10. ESP8266 Internet Controlled LED [online]. [cit. 2017-12-28]. Dostupné z: http://blog.nyl.io/esp8266-led-arduino/
11. Arduino multitasking [online]. [cit. 2017-12-28]. Dostupné z: https://learn.adafruit.com/multi-tasking-the-arduino-part-1/using-millis-for-timing
12. I2C Keypad [online]. [cit. 2017-12-28]. Dostupné z: https://www.hackster.io/venkatesh_rao/i2c-keypad-73a012
13. Insert JSON into database using PHP REST [online]. In: 18. 1. 2016 [cit. 2017-12-28]. Dostupné z: https://www.youtube.com/watch?v=4QYt2Yqo5TA
14. ESP8266 EEPROM [online]. [cit. 2017-12-28]. Dostupné z: https://circuits4you.com/2016/12/16/esp8266-internal-eeprom-arduino/
15. Over the Air transfer [online]. [cit. 2017-12-28]. Dostupné z: https://randomnerdtutorials.com/esp8266-ota-updates-with-arduino-ide-over-the-air/

---

# SEZNAM PØÍLOH
**Pøíloha è. 1: Fotodokumentace**
*   První verze bezpeènostního zaøízení složená z Arduino UNO a ESP8266-01
*   Detail na rezistorové pole sloužící k zapojení klávesnice pøes jeden analogový pin, pozdìji nahrazené I2C sbìrnicí
*   Výroba krabièky na bezpeènostní zaøízení
*   Finální podoba bezpeènostního zaøízení

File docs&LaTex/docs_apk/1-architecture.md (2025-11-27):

# Architektura a komponenty

Tento dokument popisuje architekturu a hlavní komponenty mobilní aplikace. Text je formální a věcný; implementační detaily přesahující stručné vysvětlení jsou umístěny do samostatných souborů nebo do ukázkových zdrojů v repozitáři.

## Přehled komponent

- **ApiClient**: Centralizovaný klient pro veškerou HTTP komunikaci se serverem. Obsahuje metody pro přihlášení, registraci, handshake, odesílání dat a odhlášení. Odstraňuje duplicitní síťový kód.

- **ServiceStateRepository**: Singleton objekt, který drží aktuální stav `LocationService` pomocí `StateFlow`. Umožňuje `MainActivity` (a dalším komponentám) reaktivně sledovat stav služby.

- **LoginActivity**: Zajišťuje autentizaci uživatele a registraci zařízení prostřednictvím `ApiClient`. Zabezpečeně ukládá `session_cookie` a `device_id` pomocí `EncryptedSharedPreferences`.

- **MainActivity**: Hlavní obrazovka pro prezentaci stavu služby a ovládání (start/stop, odhlášení). Sleduje aktuální stav služby pomocí `ServiceStateRepository` (`StateFlow`). Zobrazuje telemetrické údaje a stavové zprávy, včetně banneru pro serverové instrukce.

- **LocationService (foreground service)**: Odpovídá za akvizici polohy. Její životní cyklus je řízen `PowerController`. Aktualizuje stav služby v `ServiceStateRepository`.

- **SyncWorker (WorkManager)**: Provádí dávkové odesílání záznamů na `/api/devices/input` prostřednictvím `ApiClient`. Zpracovává odpovědi serveru, včetně konfiguračních změn a instrukce `TURN_OFF`, kterou předává `PowerController`.

- **HandshakeManager / HandshakeWorker**: Orchestruje komunikaci s `/api/devices/handshake` pomocí `ApiClient`. Aplikuje konfiguraci ze serveru a interpretuje `power_instruction`, kterou rovněž předává `PowerController`.

- **PowerController**: Klíčová komponenta pro správu stavového stroje napájení (`ON`/`OFF`). Centralizuje logiku pro zpracování instrukce `TURN_OFF`. Zajišťuje, že služba zůstane neaktivní, dokud není `TURN_OFF` instrukce potvrzena a zrušena serverem, nebo dokud uživatel nevynutí manuální spuštění. Spravuje příznak `pending_turn_off_ack`.

- **AppDatabase (Room)**: Lokální perzistentní úložiště pro `CachedLocation`, které slouží jako cache pro případ dočasné nedostupnosti sítě.

- **Pomocné moduly**:
  - `SharedPreferencesHelper`: Abstrakce pro bezpečné čtení a zápis do `EncryptedSharedPreferences`.
  - `ConsoleLogger`: Centralizovaný logger pro diagnostiku a monitoring v reálném čase.
  - `ServiceState`, `StatusMessages`: Datové a stavové objekty pro komunikaci.

## Datové toky a rozhraní

Základní tok dat a instrukcí je následující:

1.  **Sběr dat**: `LocationService` v aktivním stavu (`power_status = 'ON'`) získává polohu a ukládá ji jako `CachedLocation` do `Room` databáze.
2.  **Synchronizace**: `SyncWorker` se periodicky spouští, načítá dávku dat z `Room` a odesílá ji na server (`/api/devices/input`).
3.  **Zpracování odpovědi**: Server může v odpovědi poslat konfigurační změny nebo instrukci (`power_instruction`).
    -   **Změna konfigurace**: `SyncWorker` nebo `HandshakeManager` uloží nové intervaly a v případě potřeby iniciuje restart `LocationService`.
        - **Instrukce `TURN_OFF`**:
            a. `SyncWorker` nebo `HandshakeManager` zavolá `PowerController.requestTurnOff()`.
            b. `PowerController` nastaví interní stav na `OFF`, uloží příznak `pending_turn_off_ack = true` a zastaví `LocationService`.
            c. Automatické spuštění služby je blokováno, dokud je `pending_turn_off_ack` `true`. Manuální spuštění uživatelem (tlačítko) tento blok ruší.
    4.  **Potvrzení (Acknowledgement)**: `HandshakeManager` v rámci periodického handshake informuje server o svém stavu (`power_status = 'OFF'`). Když server odpoví bez `power_instruction = 'TURN_OFF'`, `HandshakeManager` zavolá `PowerController.markTurnOffAcknowledged()`, který resetuje `pending_turn_off_ack` na `false`. Tím je cyklus uzavřen a službu lze opět spustit.

## Konvence a doporučení pro implementaci

- Veškeré konstanty a názvy proměnných uvádějte ve formátu kódu (např. `TURN_OFF`, `installationId`).
- Krátké ukázky konfigurace nebo příkazů jsou prípustné; rozsáhlé kódové ukázky se ukládají mimo hlavní dokumentaci.
- Pro asynchronní a časově závislé procesy použijte jasné diagramy (sekvenční nebo časové grafy) namísto dlouhých textových popisů.

## Použité knihovny (výběr)

- Google Play Services Location
- Room
- WorkManager
- EncryptedSharedPreferences
- Gson
- LocalBroadcastManager
- Coroutines
- Material

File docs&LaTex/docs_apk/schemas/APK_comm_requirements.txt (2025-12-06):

===================================
APK Communication Requirements
===================================

1) Auth & Session
------------------
- APK klient využívá existující login endpoint (`POST /api/apk/login`).
- Účet musí být ověřený (flag `user.is_verified=true`), jinak login vrací `403`.
- Session cookie je potřeba pro uživatelské akce (registrace, logout). 
- Telemetrie a Handshake primárně využívají `device_id`, ale pokud je session cookie dostupná, je odesílána také.
- Logout (`POST /api/apk/logout`) ruší session.

2) Registrace zařízení
----------------------
- Endpoint: `POST /api/devices/register` (sjednocený).
- Payload:
  {
    "client_type": "APK",
    "device_id": "GUID/UUID",
    "name": "Device Model Name"
  }
- Server ověřuje session a mapuje ID na zařízení.

3) Handshake / Konfigurace
--------------------------
- Endpoint: `POST /api/devices/handshake`.
- Účel: Synchronizace konfigurace a správa stavu (Power State).
- Spouštění:
  1. Při startu služby (asynchronně).
  2. Periodicky (např. každých 15 min).
  3. Po dokončení odesílání dávky dat (pro okamžité potvrzení příkazů).
- Payload:
  {
    "device_id": "...",
    "client_type": "APK",
    "power_status": "ON|OFF",
    "reason": "service_start|periodic|sync_complete|manual"
  }
- Response:
  {
    "registered": true,
    "config": { "interval_gps": 60, "interval_send": 1 },
    "power_instruction": "NONE|TURN_OFF"
  }
- Klient musí respektovat `power_instruction="TURN_OFF"` zastavením služby.

4) Telemetrie (Data Input)
--------------------------
- Endpoint: `POST /api/devices/input`.
- Zpracování: SyncWorker čte data z SQLite DB.
- Formát (Batch Array):
  [
    {
      "device": "device_id",
      "latitude": 50.123,
      "longitude": 14.456,
      "timestamp": "ISO8601",
      "power_status": "ON",
      "client_type": "APK",
      "speed": 0.0,
      "accuracy": 10.5
    },
    ...
  ]
- Odpověď serveru:
  { "success": true, ... }
  - Obsahuje-li odpověď novou konfiguraci, klient ji uloží (stejně jako u Handshake).

5) Error Handling
-----------------
- 401/403: Zneplatnění session -> Logout broadcast.
- 404 (Not Registered): Zastavení služby, vyžaduje novou registraci.
- 500+: Retry politika (Worker Manager exponential backoff).

6) Lokální ukládání (Store-and-Forward)
---------------------------------------
- Data se ukládají do `LocationDao` (SQLite).
- Limit dávky: Typicky 50 záznamů na jeden request.
- Data se mažou až po potvrzení (200 OK) od serveru.
- Při chybě (Network/Server) data zůstávají v DB pro další pokus.

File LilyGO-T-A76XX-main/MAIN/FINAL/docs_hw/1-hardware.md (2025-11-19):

# Hardware a zapojení

Tento dokument popisuje hardwarové rozhraní zařízení založeného na desce LilyGO T‑Call (ESP32 + SIMCOM A7670). Obsahuje přehled periferií, mapování pinů a doporučení pro napájení a antény.

## Hlavní komponenty

- MCU: `ESP32`.
- Modem: `SIMCOM A7670` (TinyGSM profil `TINY_GSM_MODEM_A7670`).
- GPS: externí modul (např. `NEO‑6M`) připojený přes UART.
- Ovládací tlačítko: GPIO32 (servisní/OTA vstup a ruční vypnutí).
- Status LED: GPIO19 (`STATUS_LED_PIN`), oddělená od hlavního power latch obvodu.

Mapování pinů a varianty desek vycházejí z hlavičkových souborů (např. `utilities.h`). Při použití jiné varianty desky ověřte definice makra (např. `LILYGO_T_CALL_A7670_V1_0`) a případně upravte konfiguraci v `config.h`.

## GPIO a signály (stručně)

- Napájení a řízení
	- `PIN_EN` — GPIO23: power latch (držení napájení).
	- `PIN_BTN` — GPIO32: vstup tlačítka; krátký stisk spouští `graceful_shutdown()`, dlouhý stisk při bootu aktivuje servisní režim (OTA).
	- `STATUS_LED_PIN` — GPIO19: indikační LED (řadič přes rezistor).
	- `BOARD_POWERON_PIN` — GPIO12: kontrola napájení modemu.

- Externí GPS
	- GPS TX → GPIO34 (ESP32 RX)
	- GPS RX ← GPIO33 (ESP32 TX)
	- Řízení napájení GPS → GPIO5 (přes tranzistor/enable pin)

- Modem (UART)
	- `BOARD_PWRKEY_PIN` — GPIO4
	- `MODEM_TX_PIN` — GPIO26
	- `MODEM_RX_PIN` — GPIO25
	- `MODEM_RESET_PIN` — GPIO27 (aktivní LOW)
	- `MODEM_DTR_PIN` — GPIO14

	{dle modelu modemu => reference/READMElily.md}

## Napájení a úspora energie

- Firmware využívá režimy deep‑sleep mezi aktivačními cykly; parametr `sleepTimeSeconds` je konfigurovatelný.
- Modem a GPS jsou napájeny pouze po dobu nezbytnou pro akvizici a komunikaci; doporučuje se řízení napájení periferií.
- `graceful_shutdown()` provede sekvenční odpojení periferií, uloží stav a uvolní power latch.

## Schémata

- Schémata a výkresy: `schemas/` (PDF/obrázky).
- Seznam součástek: `schemas/PARTS_links.txt`(odkazy do eshopů a jejich výběr)

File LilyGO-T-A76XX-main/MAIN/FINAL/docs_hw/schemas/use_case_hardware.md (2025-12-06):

# Use Case Diagram – GPS Tracker (HW)

```mermaid
flowchart TD
    %% --- STYLY (shodné se server USE CASE) ---
    classDef actor fill:#7ce3ff;
    classDef system fill:#a8a8a8,stroke-dasharray: 5 5;
    classDef logic fill:#24ba49;
    classDef data fill:#ff3e3e;
    classDef ui fill:#f0f048;
    classDef default color:#000000;

    %% --- AKTÉŘI ---
    User((Uživatel)):::actor
    Server((Server API)):::actor

    %% --- SYSTÉM: CO UŽIVATEL VIDÍ ---
    subgraph Tracker ["GPS Tracker (HW)"]
        direction TB
        ButtonLED["Tlačítko + LED\n(krátký / dlouhý stisk)"]:::ui
        WebUI["OTA / Web konfigurace\n(SSID lotrTrackerOTA_...)"]:::ui
        Cycle["Běžný cyklus\nGPS fix → odeslat data"]:::logic
        Sleep["Deep Sleep"]:::logic
    end

    %% --- TOKY VIDITELNÉ UŽIVATELI ---
    User -->|Krátký stisk| ButtonLED
    User -->|Dlouhý stisk při startu| ButtonLED

    ButtonLED -->|Start běžný cyklus| Cycle
    ButtonLED -->|Start OTA mód| WebUI

    User -->|Nastaví APN / FW| WebUI
    WebUI -->|Uloží nastavení| Cycle

    Cycle -->|Získá polohu a odešle| Server
    Server -->|Příkazy: interval / OFF / OTA| Cycle
    Cycle -->|Hotovo → spánek| Sleep
    Sleep -->|Timer| Cycle
    User -->|Probudí tlačítkem| Sleep

    %% Vypnutí během běhu
    User -->|Krátký stisk během běhu → vypnutí| Cycle
```

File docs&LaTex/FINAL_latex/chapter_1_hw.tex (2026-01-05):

\chapter{Fyzické zařízení - tracker}
\label{chap:hw_tracker}

\section{Úvod a koncepce}
Tracker je základní součást systému, vše ostatní se zrodilo z~jeho potřeb o~rozšíření, proto je to hlavní část projektu. Jeho hlavním úkolem je pravidelně zaznamenávat polohu a~odesílat ji na~server, dle požadavků a~jednotlivých nastavení uživatelem. 
Hlavními (základními) požadavky na~zařízení jsou:

\begin{itemize}
    \setlength\itemsep{0.2em}
    \setlength\parskip{0pt}
    \setlength\parsep{0pt}
    \item Pravidelný zisk polohy (GPS fix)
    \item Pravidelné odesílání dat na~Server        
    \item Nízká spotřeba energie (pro~dlouhou výdrž na~baterii)
\end{itemize}

\noindent To jsou však pouze základní požadavky, se~kterými návrh začínal. Postupem času se poté rozvinul v~mnohem komplexnější systém chování (např. cachovaní, Deep Sleep).
Zde přikládám diagram použití pro~finální konfiguraci zařízení.

\begin{figure}[h]
    \centering
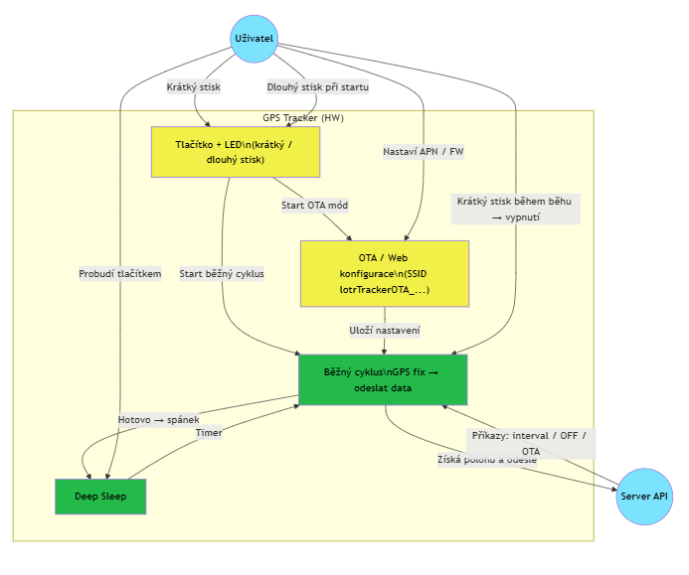
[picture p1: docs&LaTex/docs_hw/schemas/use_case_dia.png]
     
    \caption{Usecase diagram}
    \label{fig:use_case_dia}
\end{figure}

\section{POUŽITÉ TECHNOLOGIE}
\label{sec:hw_teorie}

\subsection{Mikrokontroléry (ESP32)}
Jako řídící jednotka byl zvolen čip \textbf{ESP32} od~společnosti Espressif Systems. Jedná se o~32-bitový mikrokontrolér (architektura Xtensa LX6) s~integrovanou Wi-Fi a~Bluetooth konektivitou. 
Pro~tento projekt je klíčová jeho pokročilá správa napájení, konkrétně režim \textit{Deep Sleep} viz \ref{sec:deep_sleep}.

\subsection{Mobilní komunikace a AT příkazy}
Pro~přenos dat využíváme síť LTE (4G). Komunikace mezi mikrokontrolérem a~modemem probíhá po~sériové lince (UART) pomocí standardizované sady \textbf{AT příkazů} (Hayes command set).

\subsection{Globální navigační systémy (GPS)}
Pro~získávání polohy je využit systém GPS. Modul komunikuje s~mikrokontrolérem pomocí textového protokolu \textbf{NMEA}. 
Z~celého proudu dat jsou parsovány především věty \texttt{\$GPRMC} (Recommended Minimum Specific GPS/TRANSIT Data), 
které obsahují klíčové údaje o~poloze, času a~rychlosti.

\subsection{Operační systémy reálného času (FreeRTOS)}
Pro~zajištění deterministického chování a~správy souběžných procesů (komunikace, sběr dat) je využit operační systém reálného času \textbf{FreeRTOS}. 
Ten umožňuje rozdělit aplikaci do~samostatných úloh (Tasks) s~definovanou prioritou, které jsou spravovány plánovačem.

\subsection{Souborový systém LittleFS}
Pro~ukládání konfigurace a~offline dat (cache) je využit souborový systém \textbf{LittleFS}. 
Byl zvolen pro~svou odolnost vůči výpadkům napájení (power-loss resilience), což je u~bateriového zařízení kritické. 
Díky mechanismu \textit{Copy-on-Write} nedochází k~poškození souborového systému ani při náhlém vypnutí.

\section{Návrh hardware - Výběr komponent}
\label{sec:hw_navrh}

Návrh hardwarové části systému vychází z~požadavku na~vytvoření nezávislého zařízení schopného provozu na~baterii. 

\begin{figure}[H]
    \centering
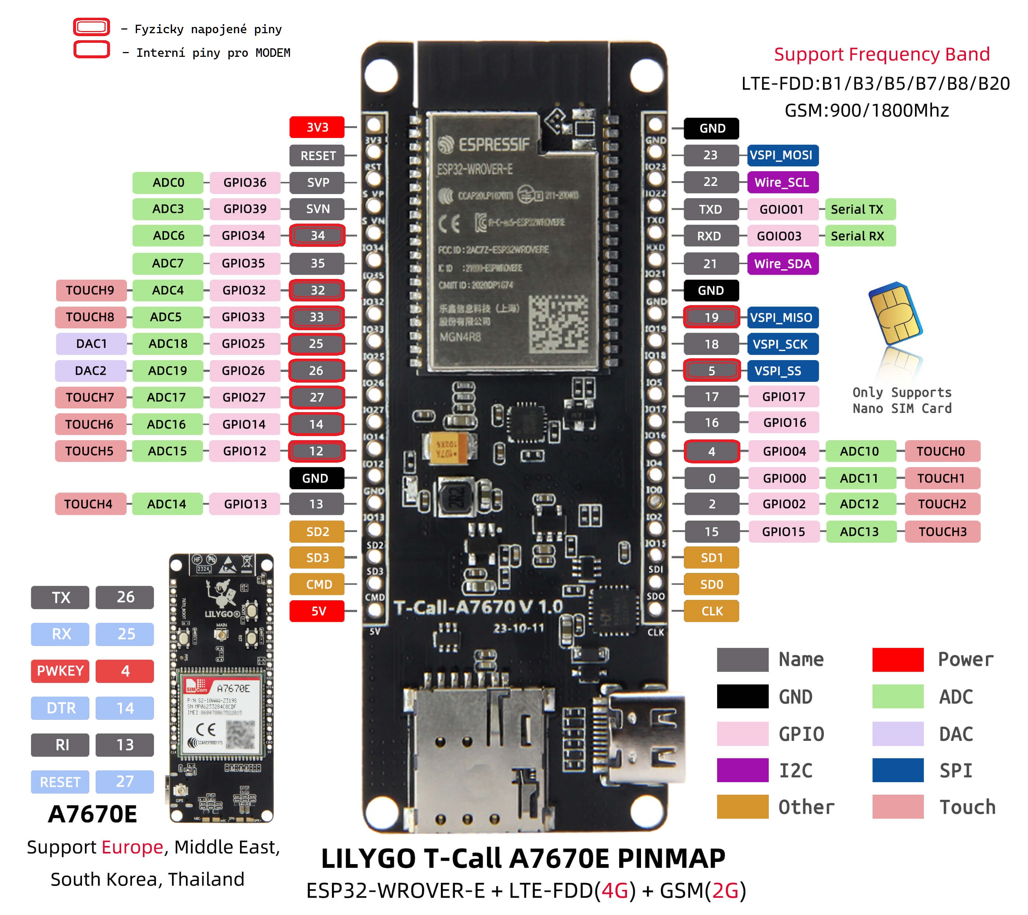
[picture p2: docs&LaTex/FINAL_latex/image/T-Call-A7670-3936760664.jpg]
     
    \caption{LilyGO T-Call V1.5 - integrované řešení ESP32 + LTE modem + použité piny}
    \label{fig:LilyGO_T-Call}
\end{figure}

\subsection{LilyGO T-Call v1.5}
Základem celého zařízení je vývojová deska \textbf{LilyGO T-Call} (verze V1.5), která v~sobě integruje výkonný mikrokontrolér ESP32 a~komunikační modem. Tato volba byla učiněna kvůli následujících kritérií:
\begin{itemize}
    \item \textbf{Integrace:} Spojení MCU a~modemu na~jedné desce eliminuje nutnost složitého propojování (bylo možné použít oddělenou desku ESP32 a~modem SIM800L, avšak zde by vznikly problémy s~napájením. Modem totiž ve~špičkách odebírá až 2A.)
    \item \textbf{Konektivita:} Použitý modem SIMCOM A7670 podporuje moderní sítě LTE (4G), což zajišťuje lepší pokrytí a~nižší latenci než zastaralé 2G moduly (např. SIM800L).
\end{itemize}

V rané fázi projektu bylo zkoušeno používat desku LilyGO SIM800L (s~podporou pouze 2G sítí), avšak kvůli vzniklému zkratu (typická to chyba) a~nemožnosti opravy desky ručně (bylo by potřeba mikropájení), přešli jsme na~desku T-call v1.5 s~modemem A7670 (podpora LTE sítí).

\subsection{ Multi-GNSS L76K modul}

Pro~získávání polohy byl zvolen externí modul \textbf{Multi-GNSS L76K} (hlavně kvůli dostupnosti).
Deska LilyGo T-call sice disponuje možností zisku GPS přes vestavěný modem, avšak externí modul nabízí lepší citlivost a
rychlost zisku dat (dle testů až 4x rychleji), také to, že takový modul byl ve~vlastnictví již před zahájením vývoje projektu, a 
tudíž nebylo nutné jej dokupovat prosadilo jeho použití. 

\begin{figure}[h]
	\centering
	\begin{subfigure}{0.35\linewidth}
		\centering
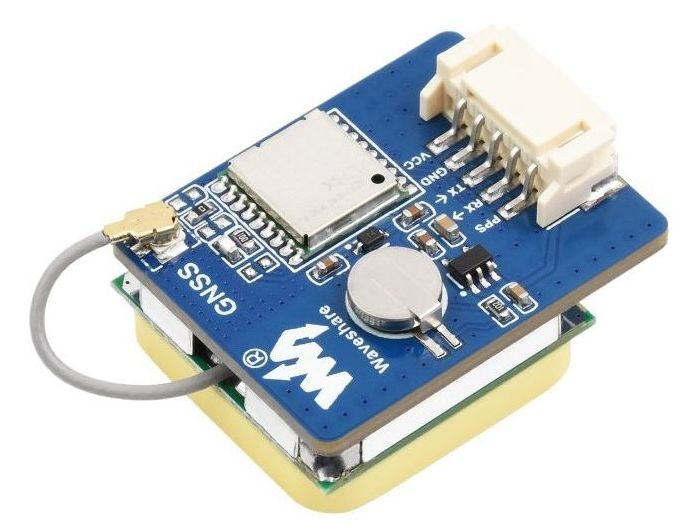
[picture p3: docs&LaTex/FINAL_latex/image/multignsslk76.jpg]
		
		\caption{Externí modul Multi-GNSS L76K}
	\end{subfigure}
	\hfill
	\begin{subfigure}{0.35\linewidth}
		\centering
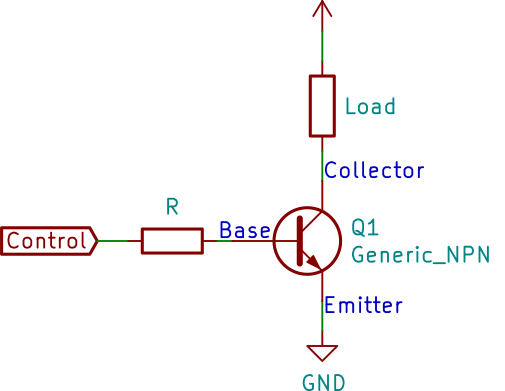
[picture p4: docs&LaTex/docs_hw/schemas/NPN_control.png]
		
		\caption{Ovladání GND}
	\end{subfigure}
	\caption{Modul GPS a zapojení pro řízení napájení}
	\label{fig:gps_module}
\end{figure}

Kvůli lepším možnostem ovládání spotřeby je modul GPS připojen přes tranzistorový spínač (NPN), který umožňuje mikrokontroléru zcela odpojit napájení GPS modulu, když není potřebný v~zapnutém stavu.
Aplikován je princip řízeného GND, sice bylo rozvažováno nad stabilnější možností ovládat VCC (takto se může v~krajních případech dostat do~modulu napětí), 
avšak z~důvodu absence vhodného PNP tranzistoru bylo zvoleno toto řešení.

\subsection{Baterie, TP4056 + MT3608}

Napájení zajišťuje Li-Ion článek typu 18650 (kapacita 3200 mAh zvolena kvůli ceně), který je dobíjen pomocí modulu s~čipem \textbf{TP4056}. Pro~zvýšení napětí z~baterie (3.7V) na~úroveň potřebnou pro~stabilní provoz desky a~GPS modulu (5 V) je použit DC-DC step-up měnič \textbf{MT3608}.

\begin{figure}[h]
    \centering
    \begin{subfigure}{0.48\linewidth}
        \centering
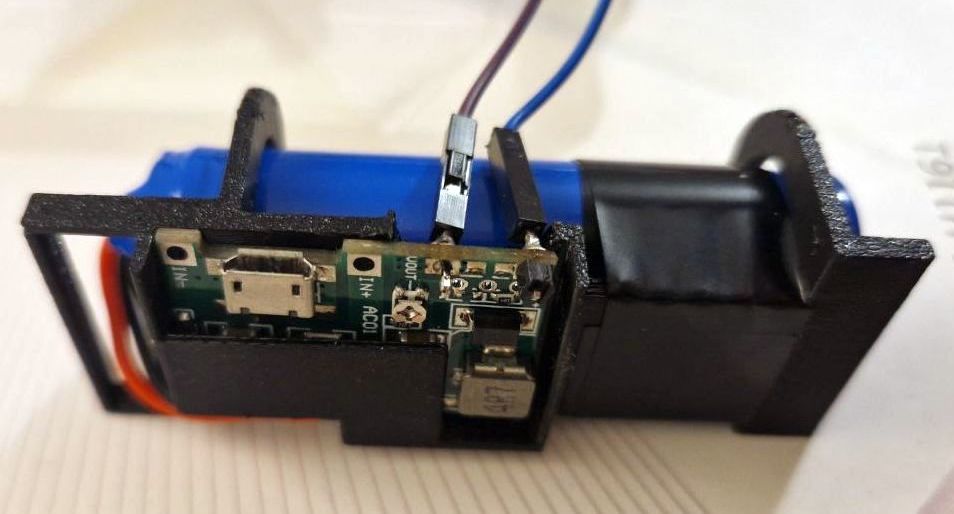
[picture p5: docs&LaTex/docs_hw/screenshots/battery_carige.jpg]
        
        \caption{TP4056 + MT3608 v~pouzdře}
        \label{fig:battery_charging_module_a}
    \end{subfigure}
    \hfill
    \begin{subfigure}{0.48\linewidth}
        \centering
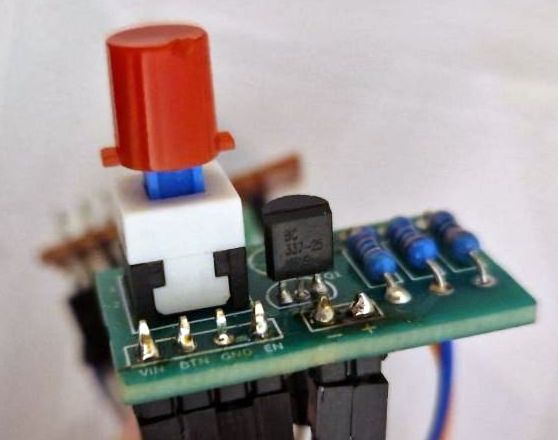
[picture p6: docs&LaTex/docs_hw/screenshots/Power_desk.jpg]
        
        \caption{Osazená deska - Power Latch modul}
        \label{fig:battery_charging_module_b}
    \end{subfigure}
    \caption{Baterie a nabíjecí modul / power latch modul - osazená deska}
    \label{fig:battery_charging_module}
\end{figure}

\subsection{Řízení napájení - Power Latch modul}
V případě zařízení jakým je tracker, nestačí pouhé "tvrdé" odpojení od~baterie vypínačem. Systém potřebuje čas na~bezpečné ukončení procesů (uzavření souborů, odhlášení ze sítě).
K tomuto účelu slouží obvod \textbf{Power Latch} (samodržný obvod). Jeho primárním cílem je umožnit mikrokontroléru převzít kontrolu nad vlastním napájením.
Navržen byl dle rady a~schématu od~známého v~oboru Elektroniky. Deska byla navržena v~EasyEDA a~vyrobena přes službu JLCPCB. Pro~úsporu peněz byla osazena součástkami ručně (cena osazení cca. 4x převyšovala cenu součástek). Proto byly součástky vybrány dle požadavků na~možnost ručního osazení (např. místo SMD vybrán mosfet v~pouzdře TO-220 atd.).

Viz implementace ve~firmware, sekce \ref{subsec:napajeni_hw}.
\begin{figure}[H]
    \centering
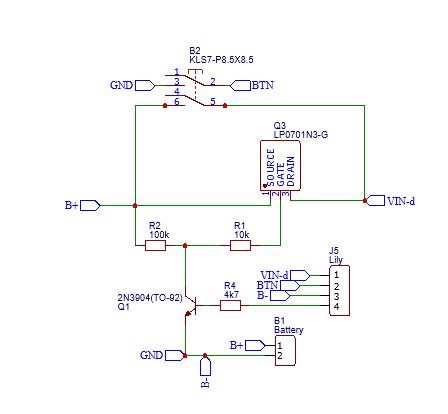
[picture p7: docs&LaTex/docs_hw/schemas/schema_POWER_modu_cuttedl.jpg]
		
		\caption{Schéma power-modul [easyEDA]}
        \label{fig:hw_schema_power}
\end{figure}

\clearpage
\section*{Výsledná sestava - schéma zapojení - piny}

\noindent GPIO piny byly přiřazeny dle dostupnosti na desce.
\begin{figure}[h]
    \centering
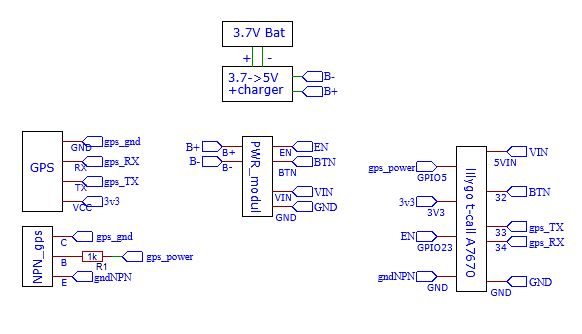
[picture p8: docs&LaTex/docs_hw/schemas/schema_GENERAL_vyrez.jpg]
     
    \caption{Blokové schéma zapojení hardwarového trackeru [easyEDA]}
    \label{fig:hw_schema_general}
\end{figure}

\begin{figure}[h]
    \centering
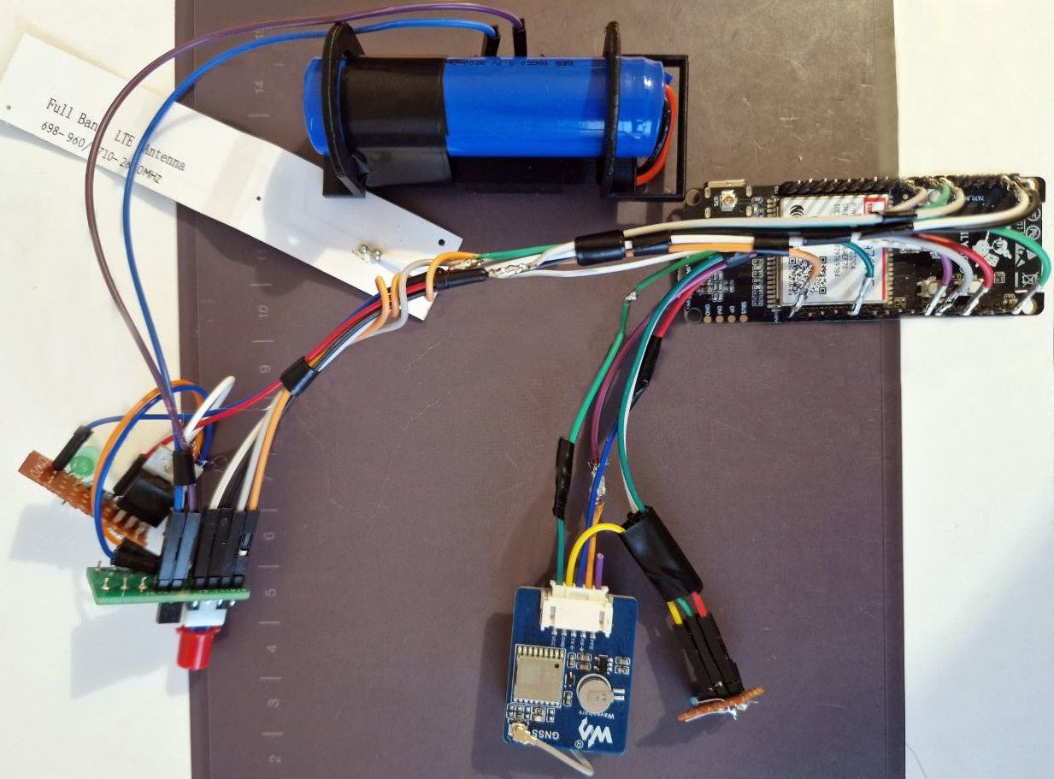
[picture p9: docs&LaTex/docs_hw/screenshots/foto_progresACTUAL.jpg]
     
    \caption{"vnitřnosti" zařízení}
    \label{fig:class_dia}
\end{figure}

\section*{Seznam použitých součástek}
\begin{itemize}
  \setlength\itemsep{0.2em}
  \setlength\parskip{0pt}
  \setlength\parsep{0pt}
  \item LilyGO T-Call V1.5 (ESP32 + LTE modem A7670)
  \item Externí GPS modul Multi-GNSS L76K (alternativně NEO-6M)
  \item LTE mikroSIM karta, datový tarif (díky minimálnímu toku dat bylo za celé období testování využito do 1MB dat)
  \item GPS anténa (u.FL/SMA dle modulu)
  \item LTE anténa (u.FL/SMA dle desky)
  
  \item Li-Ion 18650 článek
  \item Nabíjecí modul TP4056 + Step-up měnič MT3608

  \item SEMTECH BC337-25 bipolární NPN tranzistor
  \item INFINEON IRF4905PBF P-Channel MOSFET
  \item Rezistory (1 k$\Omega$, 330 $\Omega$, 100 k$\Omega$)
  \item KLS 7-P8.0x8.0-0 non lock tlačítko do DPS, 2 póly, ON-(ON) 
  \item LED dioda 3mm zelená
\end{itemize}

\section*{Návrh \uv{krabice} zařízení - model}
    
\noindent V počátcích vývoje byl vytvořen návrh možného obalu pro komponenty zařízení, avšak s tím jak byla přehodnocována struktura zapojení a vyběr použitých součástek, tak model nestíhal držet krok. 
Při testovacím tisku a složení prototypu modelu také bylo zjištěno, že "Cable managment problem" si vyžaduje mnohem více pozornosti než bylo předvídáno. Model sice byl navržen kompaktně, ale v určitých případech až přespříliš, kdy nebylo možné nějakým postupem součásti v krabičce uzavřít bez násilných úprav. 

\begin{figure}[H]
    \centering
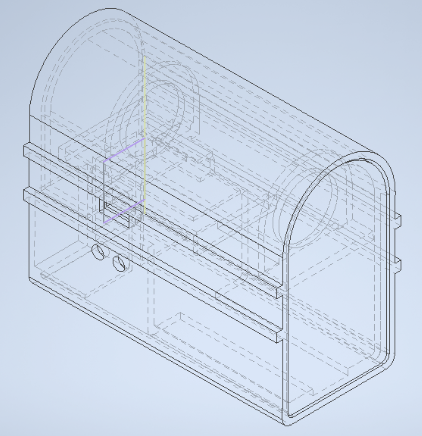
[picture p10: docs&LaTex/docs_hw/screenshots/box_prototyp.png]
     
    \caption{prototyp krabičky - průhled}
    \label{fig:box_prototyp}
\end{figure}

\clearpage

\section{Implementace firmware}
\label{sec:fw_implementace}

Software pro~mikrokontrolér byl vyvíjen v~jazyce C++ s~využitím frameworku Arduino. Jako vývojové prostředí bylo zvoleno \textbf{Visual Studio Code} s~rozšířením \textbf{PlatformIO} kvůli největší známosti.
\subsection{Architektura a použité knihovny}
Projekt je koncipován modulárně, což usnadňuje orientaci v~kódu a~případné budoucí rozšiřování. 
Zdrojový kód je rozdělen do~samostatných jednotek (hlavičkové a~zdrojové soubory) podle funkčních celků:

\begin{itemize}
  \setlength\itemsep{0.2em}
  \setlength\parskip{0pt}
  \setlength\parsep{0pt}
    \item \texttt{main.cpp}: Hlavní smyčka programu, řízení stavového automatu.
    \item \texttt{gps\_control}: Obsluha GPS modulu, parsování NMEA zpráv, řízení napájení GPS.
    \item \texttt{modem\_control}: Komunikace s~LTE modemem přes AT příkazy, správa GPRS připojení a~HTTP požadavků.
    \item \texttt{file\_system}: Abstrakce nad souborovým systémem LittleFS, ukládání a~načítání konfigurace a~offline dat.
    \item \texttt{power\_management}: Řízení spotřeby, ovládání Power Latch obvodu, přechod do~Deep Sleep.
    \item \texttt{ota\_mode}: Implementace servisního režimu, webového serveru a~OTA aktualizací.
\end{itemize}

Mezi klíčové knihovny třetích stran, na~kterých je firmware postaven, patří:
\begin{itemize}
  \setlength\itemsep{0.2em}
  \setlength\parskip{0pt}
  \setlength\parsep{0pt}
    \item \textbf{TinyGSM:} Univerzální knihovna pro~komunikaci s~GSM/LTE modemy. Pro~tento projekt byl použit profil \texttt{TINY\_GSM\_MODEM\_A7670}.
    \item \textbf{TinyGPS++:} Efektivní parser dat z~GPS modulu.
    \item \textbf{ArduinoJson:} Knihovna pro~serializaci a~deserializaci JSON objektů, používaná pro~komunikaci s~API serveru.
    \item \textbf{DeepSleep.h:} Umožňuje použití "hlubokého spánku" v~ESP32
    \item \textbf{Wifi.h:} knihovna pro~připojení k~WiFi síti, použitá v~OTA režimu
    \item \textbf{FreeRTOS , LittleFS:} již zmíněny v~sekci \ref{sec:hw_teorie}
\end{itemize}

\clearpage

\subsection{Pracovní cyklus}

Kvůli potřebě minimalizovat spotřebu baterie používá firmware funkcionalitu ESP32 : \textbf{DeepSleep} (hluboký spánek). viz \ref{sec:deep_sleep}.
Protože je použita tato funkcionalita, veškeré činnosti zařízení se odehrávají v~\textbf{\texttt{setup()}}.
Funkce \textbf{\texttt{loop()}}, obyčejně užita pro~hlavní program, je nevyužita.
Veškerý kód je proto umístěn ve~funkci \textbf{\texttt{setup()}}.

\noindent Standardní pracovní cyklus probíhá v~následujících krocích:

\begin{enumerate}
  \setlength\itemsep{0.2em}
  \setlength\parskip{0pt}
  \setlength\parsep{0pt}
    \item \textbf{Probuzení a inicializace:} Po~přivedení napájení (tlačítkem nebo časovačem) se provede inicializace periferií a~načtení konfigurace ze souborového systému.
    \item \textbf{Získání polohy (GPS Fix):} Zapne se GPS modul. Mikrokontrolér čeká na~platná data o~poloze. Pokud není fix získán do~stanoveného limitu (timeout), pokus se ukončí.
    \item \textbf{Uložení dat:} Získaná data (nebo informace o~chybě) jsou uložena do~interní paměti (LittleFS).
    \item \textbf{Odeslání dat (Upload):} Aktivuje se modem. Zařízení se připojí k~mobilní síti a~pokusí se odeslat dávku uložených záznamů na~server.
    \item \textbf{Synchronizace:} Server potvrdí přijetí dat a~případně pošle novou konfiguraci (např. změnu intervalu sledování).
    \item \textbf{Uspání (Deep Sleep):} Po~dokončení všech úloh se zařízení odpojí od~sítě, vypne periferie a~přejde do~režimu hlubokého spánku na~dobu definovanou v~konfiguraci.
\end{enumerate}

\begin{figure}[h]
    \centering
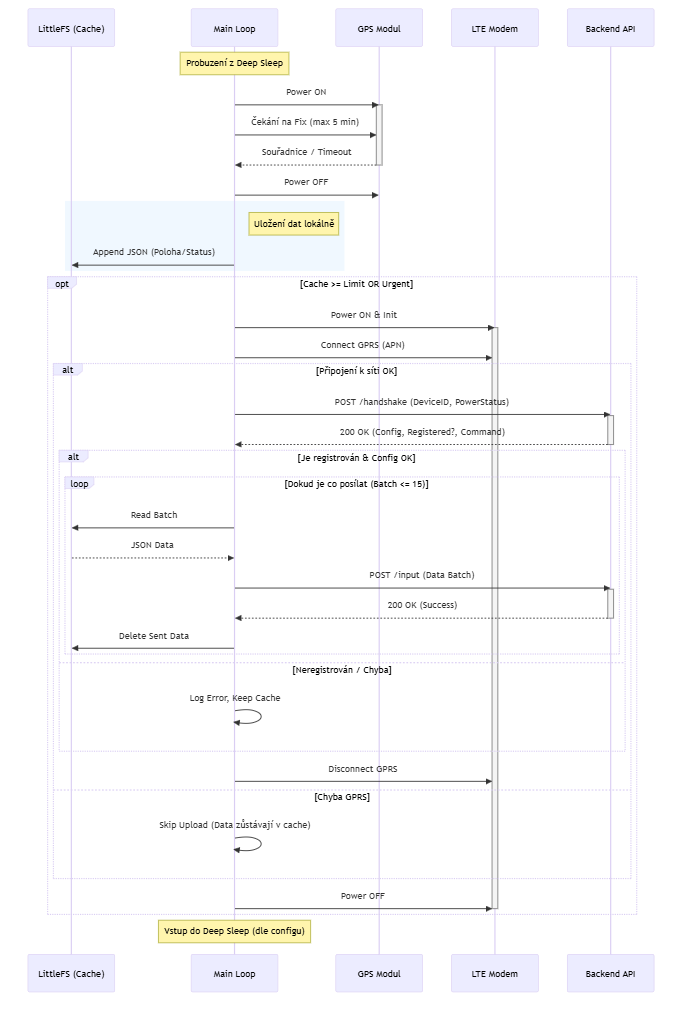
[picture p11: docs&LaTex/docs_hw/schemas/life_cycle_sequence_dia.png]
     
    \caption{sekvenční diagram životního cyklu}
    \label{fig:life_cycle_sequence_dia}
\end{figure}

\subsection{Paralelní zpracování a obsluha přerušení (FreeRTOS)}
Vzhledem k~tomu, že ESP32 disponuje dvěma jádry používáme na~něm operační systém FreeRTOS, který umožňuje efektivně rozdělit úlohy. 
V~našem případě používáme FreeRTOS pro~obsluhu funkce vypnutí zařízení. Nemohli jsme použít pouze attachInterrupt (ISR)
jelikož při přerušení nelze provádět složité akce, dlouhé I/O operace nebo vyvolávat delay.

FreeRTOS zde řeší problém souběžnosti (\uv{Concurrency}):
\begin{itemize} 
  \setlength\itemsep{0.2em}
  \setlength\parskip{0pt}
  \setlength\parsep{0pt}
    \item Když zmáčknete tlačítko, ISR se provede bleskově a~jen \uv{probudí} ShutdownTask.
   \item Tento task běží \uv{na pozadí} a~může bezpečně provádět pomalé operace (uspání modemu, uložení dat), aniž by zablokoval celý systém v~kritickém stavu ISR.
\end{itemize}

Následující ukázka z~\texttt{power\_management.cpp} ukazuje inicializaci této logiky. 
Funkce \\ \texttt{xTaskCreatePinnedToCore} vytvoří novou úlohu \texttt{ShutdownTask}, která běží na~pozadí a~čeká na~signál z~přerušení tlačítka.

\clearpage
\begin{minted}{cpp}
    void power_init() {
  if (shutdownTaskHandle != nullptr) {return;} // Already initialized
  pinMode(PIN_BTN, INPUT_PULLUP); // Use internal pull-up
  // Create the FreeRTOS task for button handling
  xTaskCreatePinnedToCore(
    ShutdownTask,     // Task function
    "ShutdownTask",   // Name of task
    4096,             // Stack size (bytes)
    NULL,             // Parameter to pass to function
    configMAX_PRIORITIES - 1, // Task priority (highest)
    &shutdownTaskHandle, // Task handle
    0                 // Core where the task should run (Core 0)
  );
  // Attach interrupt to the button pin
  attachInterrupt(digitalPinToInterrupt(PIN_BTN), on_button_isr, FALLING);
  DBG_PRINTLN(F("[POWER] Button interrupt and shutdown task initialized."));
}
\end{minted}

\subsection{Řízení napájení a Power Latch modul}
\label{subsec:napajeni_hw}
Princip celého systému napájení je následující:
\begin{enumerate}
    \setlength\itemsep{0.2em}
    \setlength\parskip{0pt}
    \setlength\parsep{0pt}
    \item Uživatel stiskne tlačítko, čímž přivede napětí do systému.
    \item ESP32 se nastartuje a okamžitě nastaví pin \texttt{PIN\_EN} na úroveň HIGH. Tím "přemostí" tlačítko a drží se pod napětím i po jeho uvolnění.
    \item Když chce zařízení přejít do vypnutého stavu (Deep Sleep nebo úplné vypnutí), provede potřebné úkony a následně nastaví \texttt{PIN\_EN} na LOW, čímž se samo odpojí.
\end{enumerate}

Následující ukázka kódu demonstruje funkci \texttt{graceful\_shutdown()}, která zajišťuje bezpečné vypnutí.

\begin{minted}{cpp}
void graceful_shutdown() {
  DBG_PRINTLN(F("\n[POWER] Shutdown requested - starting graceful power-off..."));
  // Detach interrupt to prevent any further triggers during shutdown
  detachInterrupt(digitalPinToInterrupt(PIN_BTN));
  g_shutdown_requested = true;
  power_status_mark_off();
  status_led_set(false);
  // Ask long-running tasks to abort before we tear down shared resources
  gps_request_abort();
  modem_disconnect_gprs(); modem_power_off(); // powering down modem...
  // Wait briefly for GPS loops to notice the abort request
  for (int i = 0; i < 50 && gps_is_active(); ++i) {
    vTaskDelay(pdMS_TO_TICKS(10));
  }
  gps_close_serial(); gps_power_down(); fs_end(); // ending other modules...
  // Finally, cut power to the ESP32
  digitalWrite(PIN_EN, LOW);
}
\end{minted}

\subsubsection{Režim hlubokého spánku (Deep Sleep)}
\label{sec:deep_sleep}
Kromě úplného vypnutí (Power Off) využívá zařízení také režim hlubokého spánku. Tento režim používáme pro~cyklické probouzení trackeru (jinak by bylo nutné pokaždé stisknout tlačítko pro~zapnutí, což je očividně nepoužitelné).
V~režimu Deep Sleep je vypnuto CPU, RAM i~většina periferií. Napájen zůstává pouze RTC (Real Time Clock) řadič a~malá část paměti (RTC Slow Memory). Spotřeba čipu v~tomto stavu klesá na~jednotky mikroampérů.

Probuzení z~tohoto režimu může nastat dvěma způsoby:
\begin{enumerate}
    \setlength\itemsep{0.2em}
    \setlength\parskip{0pt}
    \setlength\parsep{0pt}
    \item \textbf{Časovač (Timer Wakeup):} Po~uplynutí nastaveného intervalu (např. 10 minut).
    \item \textbf{Externí signál (Ext0 Wakeup):} Stiskem tlačítka (změna logické úrovně na~pinu GPIO32).
\end{enumerate}

Následující funkce \texttt{enter\_deep\_sleep} ukazuje konfiguraci těchto budících zdrojů před uspáním procesoru.

\begin{minted}{cpp} 
void enter_deep_sleep(uint64_t seconds) {
  DBG_PRINT(F("[SLEEP] Entering deep sleep"));
  // Detach interrupt before sleeping to prevent issues on wake
  detachInterrupt(digitalPinToInterrupt(PIN_BTN));
  // Enable wakeup by timer
  esp_sleep_enable_timer_wakeup(seconds * 1000000ULL); // microseconds
  // Enable wakeup by button (on LOW level)
  esp_sleep_enable_ext0_wakeup(static_cast<gpio_num_t>(PIN_BTN), 0);
  esp_deep_sleep_start();}
\end{minted}

\subsection{Zpracování GPS dat a parsování NMEA}
Komunikace s~GPS modulem L76K probíhá přes hardwarovou sériovou linku (UART1). Modul v~pravidelných intervalech (1 Hz dle dokumentace) odesílá textová data ve~formátu NMEA. Pro~zpracování těchto dat do~rozumné podoby jsme využili knihovnu \textbf{TinyGPS++}.

Klíčovou částí implementace je funkce \texttt{gps\_get\_fix}, která v~cyklu čte znaky ze sériového portu a~předává je parseru pomocí metody \texttt{gps.encode()}. Jakmile parser detekuje platnou větu a~aktualizuje souřadnice, zkontroluje se, zda jsou splněny podmínky pro~platný fix (validní poloha, čas a~minimální počet satelitů).
Viz. \texttt{gps\_control.cpp}.

\subsection{Správa datového úložiště (LittleFS)}
Jedním z~klíčových požadavků byla schopnost pracovat i~v~oblastech bez signálu mobilní sítě nebo v~případech výpadku připojení nebo selhání modemu. Firmware proto implementuje cachování dat.
Naměřené polohy nejsou odesílány okamžitě, ale jsou nejprve serializovány a~uloženy do~souboru \texttt{/gps\_cache.log} v~paměti flash (LittleFS). Pro~tento účel musel být systém inicializován pomocí vytvoření složky \textbf{data/} ve~složce firmwaru.
Při každém úspěšném připojení k~internetu se pak zařízení pokusí odeslat dávku nejstarších záznamů (pravidlo : FIFO - First In, First Out). Teprve po~potvrzení serverem (success: true) jsou zaznamy z~cache smazány.

\noindent   Následuje příklad funkce \texttt{fs\_init()} jež zajišťuje nabootovaní souborového systému.

\begin{minted}{cpp}
bool fs_init() {
  FsLockGuard lock;
  if (!lock.isLocked()) {
    DBG_PRINTLN(F("[FS] Failed to acquire FS lock during init."));
    return false;
  }
  if (!LittleFS.begin()) {
    DBG_PRINTLN(F("[FS] An Error has occurred while mounting LittleFS"));
    return false;
  }
  DBG_PRINTLN(F("[FS] LittleFS mounted successfully."));
  preferences.begin(PREFERENCES_NAMESPACE, false); // false for read/write
  DBG_PRINTLN(F("[FS] Preferences initialized."));
  return true;
}
\end{minted}

\section{Komunikace a data}
\label{sec:hw_komunikace}

\subsection{Komunikační protokol a zabezpečení}
Komunikace mezi zařízením a~serverem probíhá přes protokol HTTPS (modem SIMCOM A7670 umožňuje použití šifrování narozdíl třeba od~SIM800L).

Pro~navázání zabezpečeného spojení využívá modem knihovnu SSL/TLS. 
Zásadnější ovšem je samotné připojení zařízení k~GPRS síti, které je zabezpečeno pomocí "APN credentials" poskytovatele mobilních služeb.

\begin{minted}{cpp}
bool connectGPRS() {
  SerialMon.print(F("Waiting for network..."));
  if (!modem.waitForNetwork(240000L, true)) { 
    SerialMon.println(F(" fail"));
    return false;
  }
  SerialMon.println(F(" success"));

  SerialMon.print(F("Connecting to GPRS: ")); SerialMon.print(apn);
  if (!modem.gprsConnect(apn.c_str(), gprsUser.c_str(), gprsPass.c_str())) {
    SerialMon.println(F(" fail"));
    return false;
  }
  SerialMon.println(F(" success"));
  SerialMon.print(F("GPRS IP: ")); SerialMon.println(modem.getLocalIP());
  return true;
}
\end{minted}

\subsection{Struktura dat a handshake}
Komunikace se~serverem probíhá prostřednictvím REST API rozhraní. Zařízení odesílá data ve~formátu JSON (JavaScript Object Notation).

\noindent Detailní specifikace jednotlivých endpointů, struktura přenášených zpráv a~návratové kódy jsou podrobně popsány v~kapitole věnované serverové části (viz sekce \ref{sec:server_api}).

Pro~operace a~práci s~odesílanými a~přijímanými JSON daty je využita knihovna \\ \textbf{ArduinoJson}. Následující ukázka kódu z~funkce \texttt{modem\_perform\_handshake} demonstruje sestavení JSON objektu pro~úvodní "pozdrav" (handshake) a~zpracování odpovědi.

\begin{minted}{cpp}
bool modem_perform_handshake() {
  JsonDocument payloadDoc;
  payloadDoc["device_id"] = deviceID;
  payloadDoc["client_type"] = CLIENT_TYPE;
  payloadDoc["power_status"] = power_status_to_string(power_status_get());
  String payload;
  serializeJson(payloadDoc, payload);

  DBG_PRINTLN(F("[MODEM] Performing device handshake..."));
  int statusCode = 0;
  String response = modem_send_post_request(RESOURCE_HANDSHAKE, payload, &statusCode);
  // Further response handling...
\end{minted}

\subsection{Práce s Modemem a AT příkazy}
Komunikace s~LTE modemem SIMCOM A7670 probíhá prostřednictvím sériové linky (UART) pomocí sady standardizovaných AT příkazů. 
Firmware využívá knihovnu \textbf{TinyGSM}, která umožňuje využití vysokoúrovňových metod (např. \texttt{gprsConnect}, \texttt{https\_post}) místo čistých AT příkazů.

Přesto je v~některých případech nutné používat AT příkazy přímo, například při inicializaci modemu. 
Následující ukázka z~funkce \texttt{modem\_initialize} ukazuje sekvenci AT příkazů pro~ověření dostupnosti modemu a~jeho zapnutí.

\begin{minted}{cpp}
bool modem_initialize() {
    // initialization sequence ...
  SerialAT.begin(115200, SERIAL_8N1, MODEM_RX_PIN, MODEM_TX_PIN);delay(100);
  if (g_modem.testAT(500)) {
      DBG_PRINTLN(F("[MODEM] Modem responded to AT"));modemReady = true;
  } else {
      DBG_PRINTLN(F("[MODEM] No response"));modemReady = false;
  }}
\end{minted}

Knihovna TinyGSM následně volání funkcí překládá na konkrétní AT příkazy. Například volání \texttt{g\_modem.getSignalQuality()} odešle příkaz \texttt{AT+CSQ} a vyparsuje odpověď ve formátu \texttt{+CSQ: <rssi>,<ber>}.

\subsection{OTA režim a konfigurační rozhraní}
\label{sec:hw_ota_mode}

Pro~prvotní registraci, přenastavení konfigurace nebo nahrání nového firmwaru (v~BIN formě), zařízení disponuje režimem "OTA" (Over-The-Air). Tento režim se aktivuje dlouhým stiskem ovládacího tlačítka při startu zařízení (cca 2 sekundy).

Detekce tohoto stavu probíhá v~nejranější fázi funkce \texttt{setup()}, ještě před inicializací ostatních periferií. Pokud je detekován dlouhý stisk, zařízení nespustí standardní pracovní cyklus, ale přejde do~smyčky OTA režimu.

V~OTA režimu se ESP32 přepne do~role Wi-Fi přístupového bodu (Access Pointu) s~názvem \texttt{lotrTrackerOTA\_<DeviceID> (získano z~MAC adresy)} a~spustí webový server na~adrese \texttt{192.168.4.1}. Uživatel se může připojit na~tuto wifi síť a~přes webové rozhraní provádět změny.

\begin{figure}[H]
    \centering
     
    \caption{Ukázka Wi-Fi}
    \label{fig:wifi_apn_phone}
\end{figure}

Webové rozhraní nabízí následující funkce:
\begin{itemize}
  \setlength\itemsep{0.2em}
  \setlength\parskip{0pt}
  \setlength\parsep{0pt}
    \item \textbf{Registration:} Spárování nového zařízení s~uživatelským účtem.
    \item \textbf{Settings:} Konfigurace APN, adresy serveru a~portu.
    \item \textbf{Test GPRS \& Test Serverové konektivity:} Okamžité ověření konektivity modemu a~dostupnost serveru.
    \item \textbf{Firmware Update:} Nahrání nové binární verze firmware přímo z~prohlížeče. (s~následným restartem zařízení)
    \item \textbf{Clear Cache:} Pokud je potřeba, umožňuje vymazat uložená data v~paměti.(např. pokud jsou data poškozena či ve~špatném formátu a~nelze je odeslat). používá funkce LittleFS.
\end{itemize}

\begin{minted}{cpp}
  // 2. Start WiFi AP
  DBG_PRINTLN(F("Starting WiFi AP..."));
  WiFi.disconnect(true);
  WiFi.mode(WIFI_AP);
  bool apStarted = ota_password.length() == 0 ? WiFi.softAP(ota_ssid.c_str())
            : WiFi.softAP(ota_ssid.c_str(), ota_password.c_str());
  if (apStarted) {
      DBG_PRINTLN(F("WiFi AP started with configured credentials."));}
  IPAddress apIP = WiFi.softAPIP();
  DBG_PRINT(F("AP IP address: ")); DBG_PRINTLN(apIP);
\end{minted}

\subsection{Uložení konfigurace zařízení}
Konfigurace, ať již nastavena v~\texttt{/settings} (OTA režim) nebo samotné nastavení posílané Serverem, je trvale uložena v~paměti pomocí knihovny \texttt{Preferences}. Mezi klíčové parametry patří:
\begin{itemize}
  \setlength\itemsep{0.2em}
  \setlength\parskip{0pt}
  \setlength\parsep{0pt}
    \item \texttt{apn}, \texttt{gprsUser}, \texttt{gprsPass}: Nastavení mobilní sítě.
    \item \texttt{server}, \texttt{port}: Cílová adresa backendu.
    \item \texttt{sleepTimeSeconds}: Interval mezi probuzeními.
    \item \texttt{minSatellitesForFix}: Minimální počet satelitů pro~validní fix.
    \item \texttt{etc...}
\end{itemize}

\section{Obrázky}

%\begin{figure}[h]
%    \centering
%    \includegraphics[width=0.8\linewidth]{../docs_hw/screenshots/OTA_log_1.png}
%    \caption{log z OTA režimu}
%    \label{fig:ota_log}
%\end{figure}

\begin{figure}[h]
  \centering
  \begin{subfigure}{0.48\linewidth}
    \centering
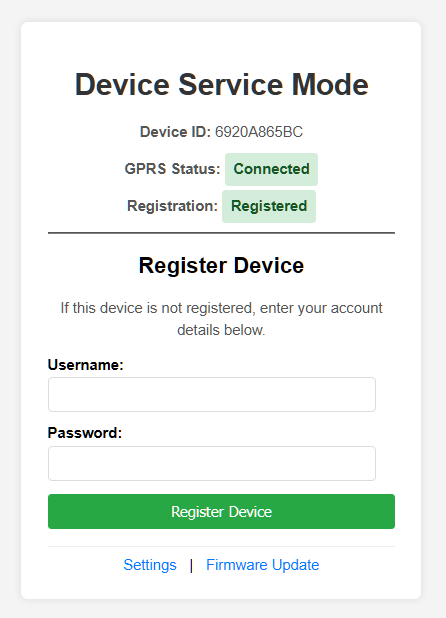
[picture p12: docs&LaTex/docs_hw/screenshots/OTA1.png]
    
    \caption{registrace}
    \label{fig:ota_Registration}
  \end{subfigure}
  \hfill
  \begin{subfigure}{0.48\linewidth}
    \centering
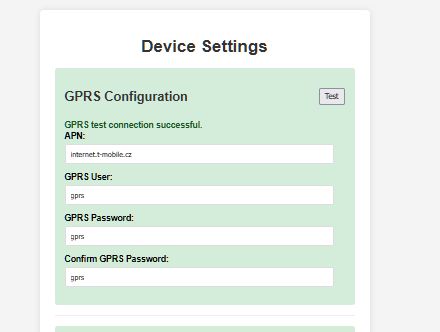
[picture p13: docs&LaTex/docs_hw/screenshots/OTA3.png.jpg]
    
    \caption{OTA režim - webové rozhraní}
  \end{subfigure}
  \caption{OTA režim - webové rozhraní}
  \label{fig:ota_Settings}
\end{figure}

%\begin{figure}[h]
%   \centering
%   \includegraphics[width=1\linewidth]{../docs_hw/schemas/process_flow.png} 
%   \caption{Stavový diagram trackeru}
%   \label{fig:process_flow_tracker}
%\end{figure}

\cleardoublepage

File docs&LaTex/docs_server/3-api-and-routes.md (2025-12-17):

# 3. API a routy

> **Důležité upozornění:** Tento dokument slouží pouze jako stručný přehled. **Autoritativní a aktuální dokumentace API** je generována automaticky ze zdrojového kódu (pomocí Swagger/OpenAPI) a je dostupná na endpointu `/api-docs` běžícího serveru. V případě rozporů má přednost Swagger dokumentace.

Tento dokument popisuje hlavní REST API a webové routy. Detailní specifikace (parametry, schémata, příklady odpovědí) jsou dostupné v Swagger UI na `/api-docs` a v `docs_server/schemas/`.

## Autorizace a middleware

- `isAuthenticated` — vyžaduje platnou session; jinak přesměruje na `/login` nebo vrátí HTTP 401 pro API.
- `isUser` — uživatel s běžnými oprávněními (ne root).
- `isRoot` — administrátorská role s vyššími právy.

Middleware implementují centrální kontrolu přístupu a validaci vstupních dat; chyby validace vrací strukturovaný JSON s popisem chyby.

## Stručný přehled rout

Webové (EJS) routy slouží UI; API routy vrací JSON a jsou určeny pro klienty (APK, HW) i frontend.

Hlavní skupiny API:

- `/api/auth` — autentizační operace (`/login`, `/register`, `/verify-email`, apod.).
- `/api/devices` — správa zařízení, příjem dat (`POST /input`), exporty, nastavení zařízení.
- `/api/settings` — změny uživatelských preferencí a bezpečnostní operace (změna hesla, smazání účtu).
- `/api/admin` — administrativní operace (pouze `isRoot`).

## Standardizace REST API (Novinka 2025)

V rámci refactoringu byly sjednoceny metody pro mazání zdrojů. Nyní jsou preferovány `DELETE` metody:

- `DELETE /api/devices/:deviceId` — Smazání zařízení.
- `DELETE /api/admin/users/:userId` — Smazání uživatele (admin).
- `DELETE /api/admin/devices/:deviceId` — Smazání zařízení (admin).
- `DELETE /api/admin/alerts/:alertId` — Smazání alertu.

*Poznámka: Původní `POST` endpointy pro mazání (např. `/api/devices/delete/:deviceId`) byly ponechány pro zpětnou kompatibilitu s HTML formuláři, ale pro API klienty se doporučuje používat `DELETE`.*

## Registrace zařízení (Unified Registration)

Registrace nových zařízení (HW i APK) je nyní centralizována pod endpointem:

- `POST /api/devices/register`

Tento endpoint přijímá parametr `client_type` (`'HW'` nebo `'APK'`) a na základě toho aplikuje příslušnou logiku ověření (pro HW vyžaduje heslo, pro APK session). Staré specifické endpointy (např. `/api/hw/register-device`) byly označeny za zastaralé nebo odstraněny ve prospěch tohoto sjednoceného přístupu.

## Klíčové endpointy (vybrané)

- `POST /api/devices/input` — přijímá dávky dat z trackerů (HW). Endpoint je veřejný (vyžaduje validní HW ID), očekávaný payload a chování viz `docs_server/schemas/` a `docs_hw/4-data-format.md`.
- `POST /api/devices/handshake` — vrací konfigurační překryvy a instrukce napájení (`NONE` | `TURN_OFF`).
- `/api/auth/*` — standardní autentizační operace; odpovědi obsahují stav a chybové kódy pro klienta.

Pro úplný seznam rout, autorizaci a příklady odpovědí použijte Swagger (`/api-docs`).

Poznámky k identifikátorům zařízení:
- V komunikaci se zařízeními (HW/APK endpointy jako `/api/devices/input` nebo `/api/devices/handshake`) se striktně vyžaduje klíč `device_id` v JSON payloadu.
- V uživatelských API pro správu (`/api/devices/settings`, `/api/devices/name`) se často používá klíč `deviceId` (camelCase).
- V administraci pro endpoint `/api/admin/delete-device/:deviceId` se očekává databázové ID zařízení (číselné `id`), nicméně novější API metody se snaží sjednotit na HW ID tam, kde je to možné. Vždy ověřte v Swaggeru.

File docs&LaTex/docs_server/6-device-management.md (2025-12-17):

# 6. Správa zařízení

Tento dokument se věnuje všem operacím souvisejícím s GPS zařízeními – od jejich registrace, přes sledování, až po konfiguraci a mazání.

- **Hlavní Controller**: `controllers/deviceController.js` (deleguje logiku na services)
- **Services**: `services/deviceService.js`, `services/locationService.js`, `services/alertService.js`, `services/geofenceService.js`
- **Routy**: `routes/devices.*.js`, `routes/hw.api.js`, `routes/apk.js`
- **Pohled**: `views/manage-devices.ejs`

## 6.1. Registrace zařízení

Primárně se používá sjednocený endpoint:

- **Unified**: `POST /api/devices/register`
  - `client_type=HW` – vyžaduje `username` + `password` a `device_id`. Endpoint provede autentizaci a přiřadí zařízení k účtu.
  - `client_type=APK` – vyžaduje aktivní session (APK login). Stačí poslat `device_id` (např. `installationId`) a volitelný název.

*Poznámka: Staré endpointy `POST /api/hw/register-device` a `POST /api/apk/register-device` byly v rámci refactoringu (2025) odstraněny nebo označeny jako deprecated. Nová integrace musí používat `POST /api/devices/register`.*

Poznámka k chování unified registrace:
- Endpoint `POST /api/devices/register` vrací `201` při úspěšném vytvoření, `200` pokud je zařízení již registrováno u stejného uživatele a `409` když zařízení patří jinému uživateli.

### Handshake

- **Endpoint**: `POST /api/devices/handshake`
- **Účel**: Zařízení (HW/APK) získá aktuální konfiguraci (`interval_gps`, `interval_send`, `mode`, `satellites`) a případnou `power_instruction` (`NONE`|`TURN_OFF`). Pokud zařízení hlásí shodu (`power_status=OFF` po instrukci `TURN_OFF`), server instrukci zruší ještě před odpovědí.
- **Výstup**: `{ "registered": true|false, "config": { ... }, "power_instruction": "NONE" | "TURN_OFF" }`
- **Legacy**: `POST /api/hw/handshake` – existuje jako alias pro `api/devices/handshake`.

Poznámka: Handshake endpoint také aktualizuje `device.device_type`, `device.power_status` a `device.last_seen`, pokud jsou tyto hodnoty zaslány v payloadu.

## 6.2. Zpracování a ukládání dat

- **Endpoint**: `POST /api/devices/input`
- **Proces (Service Layer)**:
  1.  Zařízení (HW nebo APK) odesílá data o poloze na tento endpoint.
  2.  Controller `deviceController.js` validuje vstupy a volá `LocationService.processLocationData`.
  3.  Service spustí DB transakci:
      - Uloží body do tabulky `locations` (bulk insert).
      - Aktualizuje `last_seen` a stavy (`power_status`, `device_type`) u zařízení.
      - Pokud je potvrzena instrukce vypnutí, zruší ji.
  4.  Po commitu transakce volá `GeofenceService.checkGeofence` pro asynchronní kontrolu geozón a odeslání alertů.
  
  Odpověď je `{ "success": true }` (HTTP 200).

## 6.3. Zobrazení dat

- **Live mapa**: Na hlavní stránce (`/`) se pomocí `GET /api/devices/coordinates` periodicky načítají poslední známé polohy (`LocationService.getLatestCoordinates`).
- **Historie polohy**: Na stránce `/devices` si může uživatel zobrazit historii polohy. Data se načítají z `GET /api/devices/data` (`LocationService.getDeviceHistory`) a prochází **agregací** (shlukováním) pro lepší přehlednost.

## 6.4. Konfigurace zařízení

Uživatel může na stránce `/devices` měnit nastavení pro každé zařízení (`DeviceService.updateSettings`):

- **Změna intervalů**: `POST /api/devices/settings`
  - `interval_gps`: Jak často má zařízení zjišťovat polohu.
  - `interval_send`: Po kolika zjištěných polohách má zařízení odeslat data na server.
  - `satellites`: Minimální počet satelitů pro fix.
  - `mode`: Režim `simple` vs `batch`.

## 6.5. Geofencing (Geografické ohrady)

- **Uložení ohrady**: `POST /api/devices/geofence`
- **Kontrola**: Řízena službou `GeofenceService`. Při každém přijetí nových souřadnic server zkontroluje, zda se bod nachází uvnitř uložené ohrady.
- **Spuštění poplachu**: Pokud je bod **mimo** ohradu a stav není aktivní, systém nastaví `geofence_alert_active = true`, uloží alert a odešle e‑mail (`sendGeofenceAlertEmail`).
- **Návrat do ohrady**: Pokud se zařízení vrátí dovnitř a stav byl aktivní, systém jej zruší (`geofence_alert_active = false`).

## 6.6. Poplachy (Alerts)

Všechny operace spravuje `AlertService`:

- **Vytvoření poplachu**: `GeofenceService` volá `Alert.create`.
- **Zobrazení poplachů**: Frontend se dotazuje na `GET /api/alerts` (`AlertService.getUnreadAlerts`).
- **Správa poplachů**:
  - `POST /api/alerts/read`: Označí konkrétní poplachy jako přečtené (`AlertService.markAlertsAsRead`).
  - `POST /api/alerts/read-all/:deviceId`: Označí všechny poplachy u zařízení jako přečtené.

## 6.7. Mazání zařízení

- **Endpoint**: `DELETE /api/devices/:deviceId` (nebo legacy `POST /api/devices/delete/:deviceId`)
- **Proces**: `DeviceService.deleteDevice` provede atomické smazání zařízení včetně všech závislostí (lokace, alerty) v rámci jedné transakce.

## 6.8. Export dat do GPX

- **Endpoint**: `GET /api/devices/export/gpx/:deviceId`
- **Proces**: `LocationService.getGpxData` vygeneruje XML string s historií polohy ve formátu GPX 1.1.

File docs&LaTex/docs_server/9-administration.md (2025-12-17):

# 9. Administrace

Tento dokument popisuje funkce dostupné v administrátorském rozhraní, které je určené výhradně pro správce systému (`root` uživatele).

- **Controller**: `controllers/administrationController.js` (deleguje na `AdminService`)
- **Service**: `services/adminService.js`
- **Routy**: `routes/administration.web.js`, `routes/administration.api.js`
- **Pohled**: `views/administration.ejs`

## 9.1. Přístup do administrace

Přístup je striktně omezen pomocí autorizačního middlewaru `isRoot`.

- **Endpoint**: `GET /administration`
- **Logika**: Middleware `isRoot` ověří, zda je přihlášený uživatel skutečně uživatel s `username: 'root'`.

## 9.2. Zobrazení dat

Administrátorská stránka poskytuje přímý pohled do databáze a zobrazuje čtyři hlavní tabulky: Users, Devices, Latest Locations, Alerts.

Controller (`getAdminPage`) načítá data přímo z DB modelů s podporou vyhledávání (`*Search`) a řazení (`*SortBy`).

## 9.3. Správa uživatelů

- **Endpointy**:
  - `DELETE /api/admin/users/:userId` (Standardní API)
  - `POST /api/admin/delete-user/:userId` (Legacy/Formulář)
- **Funkce**: Administrátor může smazat jakéhokoliv uživatele (kromě sebe sama).
- **Implementace**: `AdminService.deleteUserAndData` zajistí smazání uživatele. Odstranění závislých dat spoléhá na DB cascade a manuální cleanup v případě potřeby.

## 9.4. Správa zařízení

- **Endpointy**:
  - `DELETE /api/admin/devices/:deviceId` (Standardní API)
  - `POST /api/admin/delete-device/:deviceId` (Legacy/Formulář)
- **Funkce**: Administrátor může smazat jakékoliv zařízení v systému.
- **Implementace**: `AdminService.deleteDeviceAndData` provede atomické smazání zařízení a všech jeho závislostí (lokace, alerty) v transakci.

*Poznámka: `:deviceId` zde odkazuje na databázové `id` (číselné).*

## 9.5. Ověření uživatele přes admin

- **Endpoint**: `POST /api/admin/verify-user/:userId`
- **Funkce**: Nastaví `is_verified = true` pro daného uživatele (via `AdminService.verifyUser`).

## 9.6. Správa poplachů (alerts)

- **Endpointy**:
  - `DELETE /api/admin/alerts/:alertId`
  - `POST /api/admin/delete-alert/:alertId` (Legacy)
- **Implementace**: `AdminService.deleteAlert` zajistí kontrolu práv (root může vše, user jen své) a odstranění.

## 9.7. Architektura

Všechny operace jsou nyní zapouzdřeny v `services/adminService.js`. Controller pouze volá service a rozhoduje o formátu odpovědi (JSON vs Redirect).

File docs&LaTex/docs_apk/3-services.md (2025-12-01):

# Služby a synchronizace

Tento dokument popisuje servisní komponenty aplikace, jejich odpovědnosti a očekávané chování při standardních i chybových stavech. Popisy jsou stručné a koncentrované.

## LocationService

- **Role**: Popřední služba zodpovědná za akvizici polohy a její lokální persistenci.
- **Řízení stavu**: Její spuštění a běh jsou plně pod kontrolou `PowerController`.
  - Pokus o spuštění služby je ignorován, pokud `PowerController` hlásí stav `OFF` nebo pokud je aktivní příznak `pending_turn_off_ack`. Výjimkou je manuální spuštění uživatelem, které příznak `pending_turn_off_ack` zruší.
  - Při ztrátě GPS nebo externím pokynu k zastavení služba provede řádný shutdown a informuje `PowerController`.
- **Start služby (pokud je povolen `PowerController`)**:
  1. Načtení provozních parametrů (`gps_interval_seconds`, `sync_interval_count`).
  2. Spuštění `HandshakeManager` pro ověření konfigurace se serverem.
  3. Aktivace periodických aktualizací polohy z `FusedLocationProviderClient`.
- **Persistování polohy**: Každý GPS fix se uloží do `Room` databáze. Pokud počet záznamů dosáhne `sync_interval_count`, je naplánován `SyncWorker`.

## HandshakeManager / HandshakeWorker

- **Role**: Orchestrace komunikace s endpointem `/api/devices/handshake` pro synchronizaci stavu a konfigurace.
- **Hlavní funkce**:
  - Zasílá na server aktuální stav zařízení (`power_status`, verze atd.).
  - Zpracovává odpověď:
    - **Nová konfigurace**: Uloží nové intervaly a v případě potřeby (služba běží a není požadován `TURN_OFF`) iniciuje restart `LocationService`.
    - **Instrukce `power_instruction`**:
      - `TURN_OFF`: Zavolá `PowerController.requestTurnOff()`, čímž spustí proces řízeného vypnutí.
      - `NONE` (nebo chybějící instrukce): Zavolá `PowerController.markTurnOffAcknowledged()`. Tímto mechanismem se resetuje příznak `pending_turn_off_ack` a služba může být znovu spuštěna.
- **Plánování**: Periodický `HandshakeWorker` běží každých 60 minut, aby byla zajištěna pravidelná synchronizace stavu. Tento plán je zrušen, pokud `PowerController` přejde do stavu `OFF`.

## SyncWorker

- **Role**: Spolehlivé dávkové odesílání záznamů na server a aplikace serverových instrukcí.
- **Podmínky**: Běží pouze s dostupným síťovým připojením (`NetworkType.CONNECTED`).
- **Chování**:
  1. Načte dávku (max. 50) záznamů z `location_cache`. Odesílání probíhá i v případě, že `PowerController` hlásí `pending_turn_off_ack`, aby se zajistilo odeslání finálních dat před vypnutím.
  2. Odešle data na `/api/devices/input`.
  3. **Při úspěchu (HTTP 200)**:
     - Smaže odeslané záznamy z lokální databáze.
     - Zpracuje případné konfigurační změny nebo `power_instruction` stejným způsobem jako `HandshakeManager` (předává řízení `PowerController`).
     - Po dokončení dávky spustí `HandshakeManager`, aby se server dozvěděl o aktuálním stavu.
  4. **Při chybě autorizace (HTTP 401/403) nebo nenalezení zařízení (HTTP 404)**: Vyšle broadcast `FORCE_LOGOUT`, který způsobí odhlášení uživatele a vyčištění session. Dávka je smazána.
  5. **Při chybě požadavku (HTTP 400)**: Dávka je považována za vadnou a je smazána z databáze, aby neblokovala další synchronizaci.
  6. **Při ostatních serverových nebo síťových chybách**: Vrátí `Result.retry()`, aby `WorkManager` naplánoval opakování.

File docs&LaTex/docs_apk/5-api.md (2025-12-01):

# API a síťová komunikace

Základní URL je dáno `BuildConfig.API_BASE_URL` (výchozí z build.gradle) a lze je přepsat v aplikaci uložením `server_url` v EncryptedSharedPreferences (nastavitelně v `LoginActivity`{login screen}).

## Přihlášení
- Endpoint: `POST {BASE_URL}/api/apk/login`
- Tělo (JSON):
  - `identifier` (string)
  - `password` (string)
  - `installationId` (string)
- Odpověď (HTTP 200, JSON):
  - `success` (bool)
  - `device_is_registered` (bool)
  - `gps_interval` (int, sekund) – může být přítomen
  - `interval_send` (int, počet pozic) – může být přítomen
  - Set-Cookie hlavička se session cookie (aplikace si uloží první část před `;`)

- Endpoint: `POST {BASE_URL}/api/devices/register`
- Hlavičky: `Cookie: <session>`
- Tělo (JSON):
  - `client_type` = `"APK"`
  - `device_id` (string, např. installationId)
  - `name` (string, alias zařízení)
- Odpověď (HTTP 201/200, JSON):
  - `success` (bool)
  - `already_registered` (bool) – pokud bylo zařízení už zapsané
  - `interval_gps` (int) – volitelně
  - `interval_send` (int) – volitelně

### Handshake zařízení

- **Endpoint**: `POST {BASE_URL}/api/devices/handshake`
- **Hlavičky**: `Cookie: <session>`
- **Tělo (JSON)**: `device_id`, `client_type`, `power_status`, `app_version`, `platform`, `reason`
- **Odpověď (HTTP 200, JSON)**:
  - `registered` (bool)
  - `config.interval_gps` (int, volitelně)
  - `config.interval_send` (int, volitelně)
  - `power_instruction` (`"NONE"` | `"TURN_OFF"`)

**Chování klienta**:
- Pokud `registered == false`, klient provede bezpečné odhlášení (`FORCE_LOGOUT`).
- Při změně `config`, klient uloží hodnoty a restartuje `LocationService`, pokud je aktivní.
- Při obdržení `power_instruction`:
  - **`TURN_OFF`**: Klient zavolá `PowerController.requestTurnOff()`. Tím se nastaví `pending_turn_off_ack = true`, zastaví se `LocationService` a zablokuje její opětovné spuštění.
  - **`NONE`**: Klient zavolá `PowerController.markTurnOffAcknowledged()`. Tím se resetuje `pending_turn_off_ack` na `false` a službu je opět možné spustit.

### Odhlášení

- **Endpoint**: `POST {BASE_URL}/api/apk/logout`
- **Hlavičky**: `Cookie: <session>`
- **Tělo**: Prázdný JSON `{}`
- **Odpověď**: HTTP 200. Po úspěšném volání klient zneplatní lokální session.

### Odesílání poloh (dávky)

- **Endpoint**: `POST {BASE_URL}/api/devices/input`
- **Hlavičky**: `Content-Type: application/json; charset=utf-8`, `Cookie: <session>`
- **Tělo**: Pole JSON objektů (viz `4-data.md`).
- **Odpověď (HTTP 200, JSON)**: `success` (bool) a volitelně `interval_gps`, `interval_send` nebo `power_instruction`.

**Chování klienta při zpracování odpovědi**:
- **Chyba autorizace (HTTP 401/403) nebo nenalezení (HTTP 404)**: Klient iniciuje bezpečné odhlášení (`FORCE_LOGOUT`).
- **Chyba požadavku (HTTP 400)**: Klient smaže odesílanou dávku (prevence zaseknutí cache).
- **Změna konfigurace**: Aplikuje nové hodnoty a v případě potřeby restartuje `LocationService`.
- **Instrukce `power_instruction`**: Zpracuje se identicky jako v případě `handshake` endpointu (viz výše), tj. řízení přebírá `PowerController`.

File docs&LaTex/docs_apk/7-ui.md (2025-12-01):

# Uživatelské rozhraní

Tato kapitola popisuje UI komponenty aplikace s důrazem na jasnou prezentaci stavu služby a jednoduché ovládání. Uživatelé vidí pouze informace relevantní pro provoz aplikace; detaily pro vývoj jsou skryty v debug režimu.

## Login obrazovka

- Pole pro identifikaci uživatele a heslo.
- Volitelné pole pro `server_url` (přístupné přes speciální gesto v UI).
- Po úspěšném přihlášení aplikace bezpečně uloží `session_cookie`, `device_id` a provozní intervaly (`gps_interval_seconds`, `sync_interval_count`).
- Pokud zařízení není registrováno, provede se registrace vůči serveru (`POST /api/devices/register`).

## Hlavní obrazovka (MainActivity)

- **Hlavní ovládací prvek**: Přepínač (`ON`/`OFF`) pro spuštění/ukončení `LocationService`.
- **Zobrazené hodnoty**:
  - Stav služby (aktivní / zastavená / pozastaveno serverem).
  - Odpočet do dalšího odeslání dat (Timer).
  - Počet záznamů v lokální cache.
  - Indikátor provozního stavu (`power_status`).
- **Speciální UI stavy**:
  - **Banner se serverovou instrukcí**: Pod hlavním přepínačem se zobrazuje informační banner (`serverInstructionBanner`), pokud aplikace čeká na potvrzení instrukce `TURN_OFF`. Informuje uživatele, že služba byla pozastavena na pokyn serveru.
  - **Deaktivovaný přepínač**: Hlavní přepínač je neaktivní (disabled), pokud je příznak `pending_turn_off_ack` nastaven na `true`. Tím se zabrání konfliktu mezi uživatelským vstupem a serverovou instrukcí.
- **Interakce**:
  - **Krátký stisk přepínače**: Spustí nebo zastaví `LocationService`, pokud to `PowerController` dovolí (tj. není aktivní `pending_turn_off_ack`).
  - **Dlouhý stisk přepínače**: Zobrazí potvrzovací dialog pro odhlášení. Po potvrzení se vyčistí lokální session a zavolá se `POST /api/apk/logout`.
  - **Dlouhý stisk na konzoli**: Otevře dialog pro filtrování logů podle úrovně (Debug, Info, Warn, Error).

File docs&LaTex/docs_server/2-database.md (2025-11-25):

# 2. Databáze

Tento dokument detailně popisuje databázové schéma, jednotlivé tabulky (modely) a jejich vzájemné vztahy.

## 2.1. Přehled

- **Systém**: MySQL
- **ORM**: Sequelize
- **Inicializace**: Schéma databáze a základní data jsou definovány v souboru `init-db.sql`, který se automaticky spouští při prvním startu `mysql` kontejneru v Dockeru.

## 2.2. Schéma a modely

Následuje popis jednotlivých tabulek a jejich reprezentace v Sequelize modelech.

### Tabulka `users`

Ukládá informace o uživatelských účtech.

- **Model**: `models/user.js`
- **Klíčové sloupce**:
  - `id`: Primární klíč (PK).
  - `username`, `email`: Unikátní identifikátory uživatele.
  - `password`: Hashované heslo pro lokální účty (u OAuth může být prázdné, dokud si uživatel nenastaví heslo).
  - `is_verified`: Flag, zda byl e-mail uživatele ověřen.
  - `verification_code`, `verification_expires`: Dočasný kód a jeho expirace pro ověření e‑mailu nebo specifické procesy.
  - `pending_email`: Dočasně uložený nový e‑mail čekající na ověření.
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

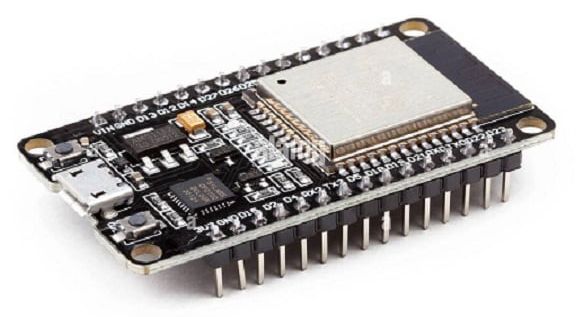
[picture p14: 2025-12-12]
docs&LaTex/FINAL_latex/image/ESP32.jpg

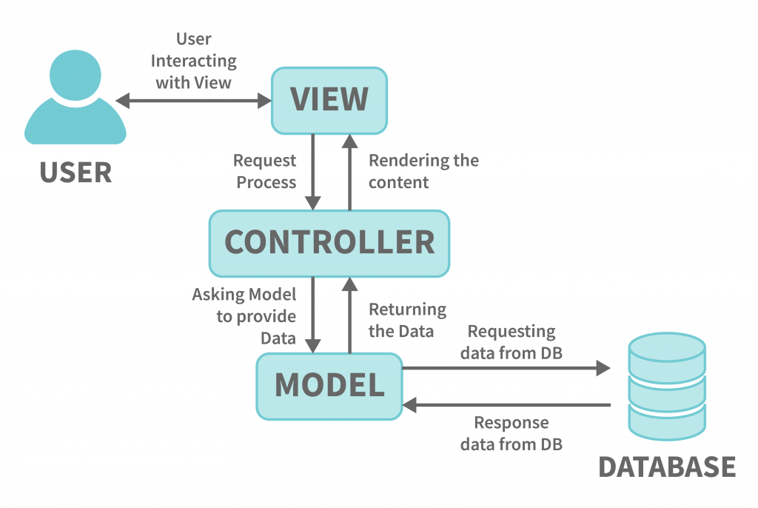
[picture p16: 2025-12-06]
docs&LaTex/FINAL_latex/image/MVC_arch.png

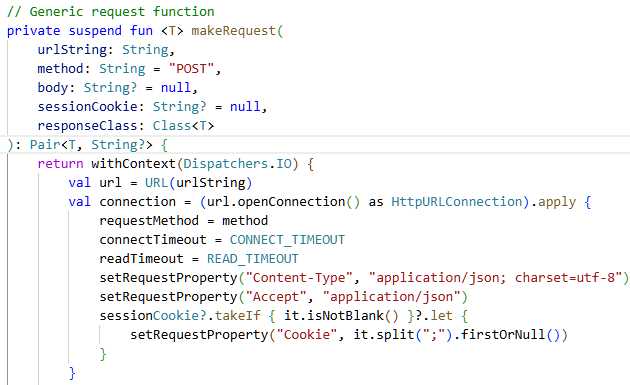
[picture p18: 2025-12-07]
docs&LaTex/docs_apk/screenshots/api_client.png

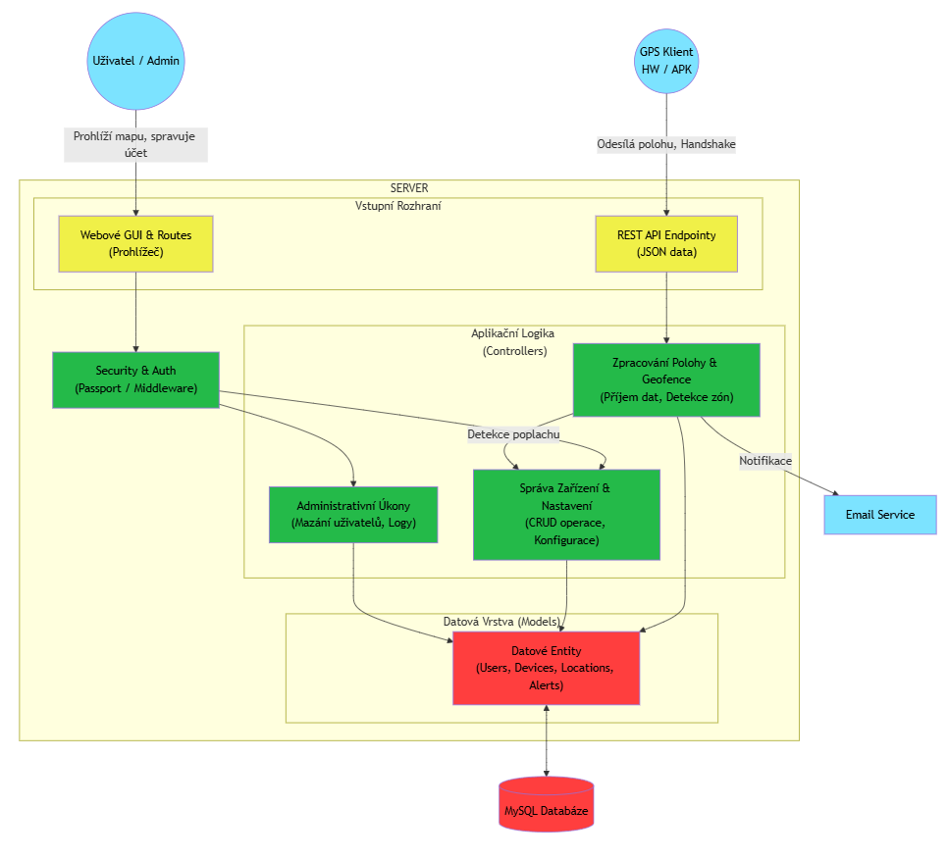
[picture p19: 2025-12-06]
docs&LaTex/docs_server/schemas/Use_case_diagram.png

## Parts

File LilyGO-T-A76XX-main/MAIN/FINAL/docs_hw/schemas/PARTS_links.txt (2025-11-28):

ACTUAL
--------------------
https://www.laskakit.cz/nabijecka-li-ion-clanku-tp4056-boost-mt3608/
https://lilygo.cc/products/t-call-v1-4
https://botland.cz/gps-moduly/22732-multi-gnss-polohovaci-modul-l76k-gps-beidou-bds-glonass-qzss-waveshare-23721.html

HISTORIC
--------------------
https://www.laskakit.cz/lilygo-ttgo-t-call-v1-3-esp32-sim800l-wifi-gprs-modul/
https://www.laskakit.cz/nabijecka-li-ion-clanku-tp4056-s-ochranou-microusb/

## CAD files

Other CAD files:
Box_ipt/3DTISK-sestava-charger-battery.iam
Box_ipt/Assembly1.iam
Box_ipt/OldVersions/3DTISK-sestava-charger-battery.0002.iam
Box_ipt/OldVersions/Assembly1.0002.iam
Box_ipt/OldVersions/Part4.0015.ipt
Box_ipt/OldVersions/schranka.0014.ipt
Box_ipt/OldVersions/sestava-charger-battery.0016.iam
Box_ipt/OldVersions/víko - kopie.0004.ipt
Box_ipt/OldVersions/víko.0008.ipt
Box_ipt/Part2.ipt
Box_ipt/Part4-2option.ipt
Box_ipt/battery.ipt
Box_ipt/charger.ipt
Box_ipt/lily+gps.ipt
Box_ipt/schranka.ipt
Box_ipt/sestava-charger-battery.iam
Box_ipt/víko - kopie.ipt
Box_ipt/víko.ipt

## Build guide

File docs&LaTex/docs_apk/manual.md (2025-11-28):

# Uživatelský manuál - GPS Reporter App

Tato aplikace slouží pro sledování polohy zařízení a její odesílání na centrální server. Je navržena tak, aby fungovala spolehlivě na pozadí i při vypnuté obrazovce.

## 1. První spuštění a Přihlášení

Při prvním spuštění vás uvítá přihlašovací obrazovka.

1.  **Server URL:** Ve výchozím stavu je nastavena produkční adresa.
    *   *Tip:* Pokud potřebujete změnit URL serveru, **dlouze podržte nadpis "GPS Reporter"** v horní části obrazovky. Zobrazí se skryté pole pro editaci URL.
2.  **Přihlašovací údaje:** Zadejte své uživatelské jméno a heslo.
3.  **Installation ID:** Aplikace si automaticky vygeneruje unikátní 10místné ID zařízení. Toto ID se při prvním přihlášení zaregistruje k vašemu účtu.

## 2. Hlavní obrazovka a Ovládání

### Spuštění sledování (START)
Stiskněte velké tlačítko **ON**. Aplikace provede sérii kontrol:
1.  **Zapnutá GPS:** Pokud je GPS vypnutá, budete vyzváni k jejímu zapnutí.
2.  **Oprávnění:** Postupně se zobrazí žádosti o oprávnění.
    *   **Poloha (Přesná):** Nutné pro fungování.
    *   **Notifikace:** Nutné pro zobrazení stavu v liště (Android 13+).
    *   **Poloha na pozadí (DŮLEŽITÉ):** Aplikace vás vyzve k nastavení "Povolit vždy" (Allow all the time). **Bez tohoto oprávnění nebude aplikace fungovat, když zhasnete displej.**

### Zastavení sledování (STOP)
Stiskněte tlačítko **OFF**.
*   **Standardní režim:** Sledování se okamžitě ukončí.
*   **Řízený režim:** Pokud server vyžaduje potvrzení ukončení jízdy, tlačítko se změní na stav "Čekám na potvrzení". Aplikace se nevypne úplně, dokud server (dispečer) ukončení nepotvrdí nebo dokud neuplyne časový limit.

### Odhlášení
Pro odhlášení uživatele **dlouze podržte tlačítko ON/OFF**.

## 3. Informační panel

Na hlavní obrazovce vidíte několik důležitých údajů:

*   **Status:** Aktuální stav služby (např. "Tracking active", "Waiting for GPS").
*   **Last Connection:** Výsledek posledního pokusu o spojení se serverem.
*   **Countdown:** Odpočet do příštího odeslání dat.
*   **Cached positions:** Počet bodů uložených v telefonu, které čekají na odeslání (např. když není signál).
    *   *Pokud je číslo vysoké (>100), zkontrolujte připojení k internetu.*

## 4. Diagnostika a Řešení problémů

### Konzole (Logy)
Ve spodní části obrazovky běží výpis událostí (logů).
*   **Možnosti zobrazení:** Dlouhým stisknutím oblasti logů (karty) otevřete menu, kde můžete filtrovat úroveň detailů (INFO, DEBUG, ERROR) nebo logy smazat.

### Časté problémy

**Aplikace přestala sledovat po zhasnutí displeje:**
*   Příčina: Pravděpodobně nemáte povoleno oprávnění "Poloha na pozadí" nebo systém Android aplikaci uspal pro úsporu baterie.
*   Řešení: Jděte do Nastavení telefonu -> Aplikace -> GPS Reporter -> Oprávnění -> Poloha a ujistěte se, že je zaškrtnuto **"Povolit vždy"**.

**Stav "Waiting for TURN_OFF confirmation" nezmizí:**
*   Příčina: Aplikace odeslala požadavek na ukončení, ale server neodpovídá (žádný signál) nebo dispečer jízdu neukončil.
*   Řešení: Zkontrolujte internet. Pokud problém přetrvává, kontaktujte dispečink.

**Chyba "Device not registered":**
*   Pokud se zobrazí tato hláška, vaše instalace byla na serveru smazána nebo zablokována. Aplikace vás automaticky odhlásí. Je nutné se znovu přihlásit (což provede novou registraci).

## 5. Technické detaily

*   **Databáze:** Data se ukládají lokálně do SQLite. Při ztrátě signálu se data neztratí, odešlou se, jakmile bude síť dostupná.
*   **Intervaly:** Interval snímání GPS (default 60s) a odesílání (default po 1. bodu) jsou řízeny centrálně serverem. Po přihlášení se mohou změnit.

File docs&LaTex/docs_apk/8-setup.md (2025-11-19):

# Build a spuštění

Tento dokument popisuje základní požadavky a postup pro sestavení a spuštění Android klienta pro vývoj a testování.

## Požadavky

- Android Studio (Giraffe nebo novější).
- Android SDK 35.
- Cílová zařízení: Android 8.0 (API 26) a vyšší.

## Postup sestavení a nasazení

1. Otevřete projekt v Android Studiu (adresář projektu s modulem `apk/main`).
2. Nechte stáhnout a synchronizovat závislosti Gradle.
3. Sestavte aplikaci a nasazení proveďte na fyzickém zařízení nebo emulátoru s povolenými Google Play služby, pokud jsou vyžadovány.
4. Při prvním spuštění udělte požadovaná oprávnění (především lokalizace a oprávnění pro provoz na pozadí, pokud je cílové API vyžaduje).
5. Přihlaste se; pokud je zařízení neregistrované, proběhne automatická registrace vůči serveru.

## Konfigurace serveru

- Výchozí `API_BASE_URL` je definován v {login screen}; hodnota se uloží do `EncryptedSharedPreferences` pod klíčem `server_url`.

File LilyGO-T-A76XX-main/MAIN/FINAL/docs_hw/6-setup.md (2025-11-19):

## Build a nasazení (PlatformIO)

1. Otevřete root projektu a načtěte jej v VS Code s nainstalovaným PlatformIO.
2. Zkontrolujte `platformio.ini` (výchozí `default_envs = T-Call-A7670X-V1-0` a `src_dir = MAIN`).
3. Inicializujte souborový systém (Upload Filesystem Image) pro `LittleFS` před prvním nasazením.
4. Nahrajte firmware (`Upload`).

## První spuštění a servisní režim

Servisní (OTA) režim slouží pro konfiguraci a registraci zařízení bez nutnosti fyzického přístupu k sériovému rozhraní.

1. Při napájení držte tlačítko (GPIO32) stisknuté minimálně 2 s pro vstup do servisního režimu.
2. Zařízení aktivuje Wi‑Fi AP (výchozí SSID: `lotrTrackerOTA_<DeviceID>`); připojte se a otevřete `http://192.168.4.1`.
3. V rozhraní zadejte přihlašovací údaje a konfiguraci sítě pro OTA/registraci.
4. Po úspěšné registraci zařízení restartujte a ověřte běh v tracker režimu.

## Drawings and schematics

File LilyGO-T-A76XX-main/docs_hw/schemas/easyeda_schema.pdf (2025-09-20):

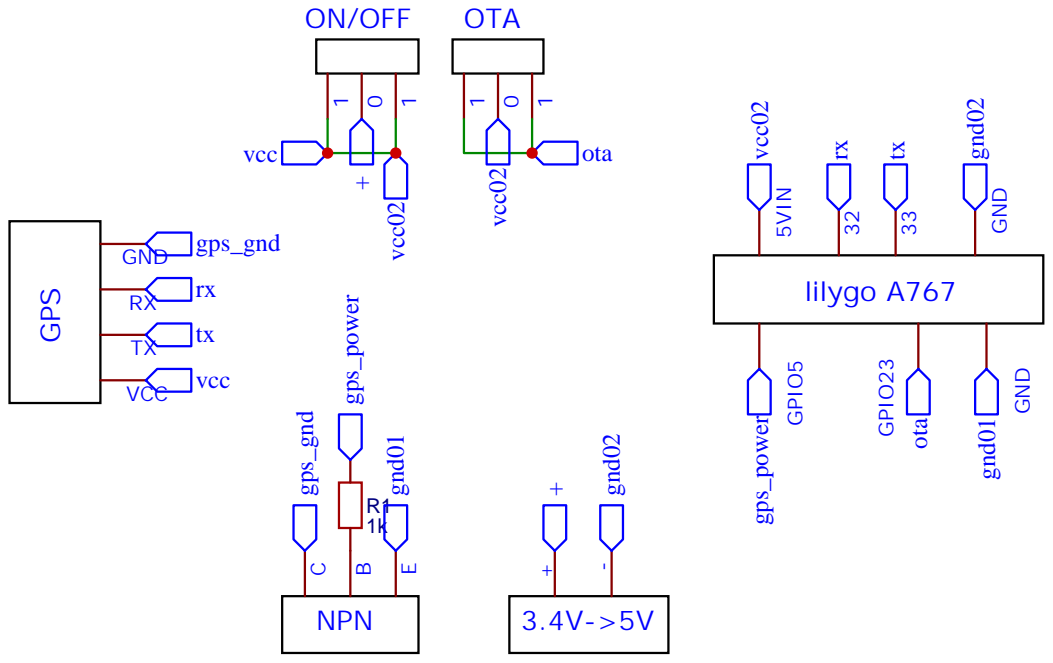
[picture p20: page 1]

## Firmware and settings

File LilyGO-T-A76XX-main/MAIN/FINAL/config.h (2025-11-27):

#pragma once

#ifdef ARDUINO
#include <Arduino.h>
#else
#include <stdint.h>
#endif

// --- Hardware Variant Selection ---
// Define the LilyGO board variant to pull in the correct pin map from utilities.h.
// Adjust the macro below if you are compiling for a different hardware revision.
#ifndef LILYGO_T_CALL_A7670_V1_0
#define LILYGO_T_CALL_A7670_V1_0
#endif

#include "utilities.h"

// Override status LED mapping to use dedicated GPIOs (Board power remains on GPIO12)
#undef STATUS_LED_PIN
#define STATUS_LED_PIN 19
#undef STATUS_LED_ON_LEVEL
#define STATUS_LED_ON_LEVEL HIGH
#undef STATUS_LED_OFF_LEVEL
#define STATUS_LED_OFF_LEVEL LOW

// --- Pin Definitions ---
#define PIN_EN          23  // ESP32 pin to hold power ON (HIGH = ON, LOW = OFF)
#define PIN_BTN         32  // ESP32 pin for the power/mode button (connected to GND, uses internal pull-up)
#define GPS_RX_PIN      34  // ESP32 RX <- GPS TX (input-only pin is sufficient)
#define GPS_TX_PIN      33  // ESP32 TX -> GPS RX
#define GPS_POWER_PIN   5   // ESP32 pin to control power to GPS module (via transistor)

// --- Button Logic Constants ---
const uint32_t BTN_DEBOUNCE_MS      = 80;    // Debounce time for button press in milliseconds
const uint32_t BTN_SHORT_PRESS_MS   = 500;   // Minimum duration for a short press (e.g., for shutdown)
const uint32_t BTN_LONG_PRESS_MS    = 2000;  // Minimum duration for a long press (e.g., for OTA mode)

// --- GPS Configuration ---
#define GPS_BAUD_RATE           9600
#define SAT_THRESHOLD           1   // Minimum satellites for a valid fix
const unsigned long GPS_ACQUISITION_TIMEOUT_MS = 5 * 60 * 1000; // 5 minutes for GPS fix attempt

// --- GPRS Configuration (Default values, can be overwritten by Preferences) ---
#define DEFAULT_APN             "internet.t-mobile.cz"
#define DEFAULT_GPRS_USER       "gprs"
#define DEFAULT_GPRS_PASS       "gprs"

// --- Server Configuration (Default values, can be overwritten by Preferences) ---
#define DEFAULT_SERVER_HOST     "lotr-system.xyz"
#define DEFAULT_SERVER_PORT     443
#define RESOURCE_POST           "/api/devices/input"
#define RESOURCE_REGISTER       "/api/devices/register"
#define RESOURCE_HANDSHAKE      "/api/devices/handshake"
#define CLIENT_TYPE             "HW"

// --- File System & Preferences ---
#define CACHE_FILE              "/gps_cache.log"
#define PREFERENCES_NAMESPACE   "gps-tracker"
#define KEY_BATCH_SIZE          "batch_size"
#define KEY_BATCH_THRESHOLD     "batch_threshold"

// --- Batch Sending Configuration ---
// Minimum number of cached records before attempting a modem session to send data.
// A value of 1 means try to send every cycle.
#define DEFAULT_BATCH_SEND_THRESHOLD 1

// --- Device & Sleep Configuration ---
#define DEFAULT_DEVICE_NAME     "NEO-6M_A7670E"
const uint64_t DEFAULT_SLEEP_SECONDS = 60;

// --- OTA Configuration (Default values, can be overwritten by Preferences) ---
#define DEFAULT_OTA_SSID        "lotrTrackerOTA#1"
#define DEFAULT_OTA_PASSWORD    ""

// --- Serial Debug ---
#define SerialMon Serial
// #define TINY_GSM_DEBUG SerialMon // Uncomment for TinyGSM internal debug
// #define DUMP_AT_COMMANDS // Uncomment to see all AT commands

#define DEBUG_MODE true

#if DEBUG_MODE
  #define DBG_BEGIN(...)    SerialMon.begin(__VA_ARGS__)
  #define DBG_PRINT(...)    SerialMon.print(__VA_ARGS__)
  #define DBG_PRINTLN(...)  SerialMon.println(__VA_ARGS__)
  #define DBG_PRINTF(...)   SerialMon.printf(__VA_ARGS__)
  #define DBG_FLUSH()       SerialMon.flush()
#else
  #define DBG_BEGIN(...)
  #define DBG_PRINT(...)
  #define DBG_PRINTLN(...)
  #define DBG_PRINTF(...)
  #define DBG_FLUSH()
#endif

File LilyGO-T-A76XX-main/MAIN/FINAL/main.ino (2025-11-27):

#include <Arduino.h>
#include <WiFi.h>
#include <ArduinoJson.h>
#include "config.h"
#include "power_management.h"
#include "ota_mode.h"
#include "file_system.h"
#include "gps_control.h"
#include "modem_control.h"

// Global variables (declared extern in respective headers)
extern String deviceID;
extern String deviceName;
extern uint64_t sleepTimeSeconds;
extern bool isRegistered;
extern bool gpsFixObtained;
extern double gpsLat, gpsLon, gpsSpd, gpsAlt, gpsHdop;
extern int gpsSats;
extern uint16_t gpsYear;
extern uint8_t gpsMonth, gpsDay, gpsHour, gpsMinute, gpsSecond;

RTC_DATA_ATTR int cycleCounter = 0; // Counts boot cycles, survives deep sleep

// Forward declaration for the main work cycle function
void work_cycle();

void setup() {
  // 1. Hold power ON
  power_on();

  // 2. Initialize Serial communication
  DBG_BEGIN(115200);
  delay(100);
  DBG_PRINTLN(F("\n[BOOT] Device started."));

  // 3. Check for long press to enter OTA mode
  // This check needs to happen very early, before other initializations
  // and before the button ISR is fully active for normal operation.
  // We check the button state directly here.
  pinMode(PIN_BTN, INPUT_PULLUP); // Ensure button pin is configured (internal pull-up enabled)
  delay(100); // Small delay for pin to stabilize

  if (digitalRead(PIN_BTN) == LOW) {
    DBG_PRINTLN(F("[BOOT] Button pressed at startup. Checking for long press..."));
    delay(200); // Debounce delay
    unsigned long press_start_time = millis();

    // Wait while the button stays low or until the long-press threshold is reached.
    while ((millis() - press_start_time) < BTN_LONG_PRESS_MS) {
      if (digitalRead(PIN_BTN) != LOW) {
        break; // Released before long-press threshold
        unsigned long lastBlink = millis();
        while (digitalRead(PIN_BTN) == LOW) {
          if (millis() - lastBlink >= 250) {
            lastBlink = millis();
            status_led_toggle();
          }
          delay(10);
        }
        delay(150); // Debounce release
        status_led_set(true);
      }
      delay(10);
    }

    if (digitalRead(PIN_BTN) == LOW) {
      DBG_PRINTLN(F("[BOOT] Long press detected. Entering OTA mode."));
      // Provide visual feedback while waiting for the button to be released
      unsigned long lastBlink = millis();
      while (digitalRead(PIN_BTN) == LOW) {
        if (millis() - lastBlink >= 250) {
          lastBlink = millis();
          status_led_toggle();
        }
        delay(10);
      }
      delay(150); // Debounce release
      status_led_set(true);
      start_ota_mode(); // This function will loop indefinitely
      while (true) { delay(1000); } // Should not be reached
    }

    DBG_PRINTLN(F("[BOOT] Button released before long press threshold. Continuing normal boot."));
  }

  // If not in OTA mode, proceed with normal boot and power management initialization
  DBG_PRINTLN(F("[BOOT] Normal operating mode."));

  // Initialize power management (ISR and FreeRTOS task for button handling)
  power_init();

  // Handle wake-up cause (for debugging/logging)
  esp_sleep_wakeup_cause_t wakeup_cause = esp_sleep_get_wakeup_cause();
  switch (wakeup_cause) {
    case ESP_SLEEP_WAKEUP_EXT0:  DBG_PRINTLN(F("[BOOT] Wakeup by EXT0 (button).")); break;
    case ESP_SLEEP_WAKEUP_TIMER: DBG_PRINTLN(F("[BOOT] Wakeup by timer.")); break;
    case ESP_SLEEP_WAKEUP_UNDEFINED: DBG_PRINTLN(F("[BOOT] Power-on reset or undefined wakeup cause.")); break;
    default: DBG_PRINTF("[BOOT] Wakeup cause: %d\n", wakeup_cause); break;
  }

  // Start the main work cycle
  work_cycle();

  // After work cycle, enter deep sleep
  // This will be replaced by actual sleep time from config
  if (power_instruction_ack_pending()) {
    DBG_PRINTLN(F("[MAIN] Power instruction acknowledgement still pending. Staying awake for retry."));
    return;
  }
  if (isRegistered) {
    DBG_PRINT(F("[MAIN] Device is registered. Next update in approx. ")); DBG_PRINT(sleepTimeSeconds); DBG_PRINTLN(F(" seconds."));
    enter_deep_sleep(sleepTimeSeconds);
  } else {
    DBG_PRINTLN(F("[MAIN] DEVICE NOT REGISTERED. Powering down permanently."));
    DBG_PRINTLN(F("[MAIN] Please use OTA mode to register the device."));
    graceful_shutdown(); // Power off indefinitely
  }
}

void loop() {
  // This will not be reached as the device either enters OTA mode or deep sleep
}

void work_cycle() {
  DBG_PRINTLN(F("[MAIN] Starting work cycle."));
  if (shutdown_is_requested()) {
    DBG_PRINTLN(F("[MAIN] Shutdown already requested. Aborting work cycle."));
    return;
  }

  // 1. Initialize Filesystem and Preferences
  if(!fs_init()){
      DBG_PRINTLN(F("[MAIN] File system initialization failed. Cannot proceed."));
      graceful_shutdown(); // Power off if FS fails
      return;
  }
  fs_load_configuration(); // Load configuration into global variables
  if (shutdown_is_requested()) {
    DBG_PRINTLN(F("[MAIN] Shutdown requested after configuration load. Aborting work cycle."));
    return;
  }

  // Set Device ID from MAC Address, this is permanent and unique
  String mac = WiFi.macAddress();
  mac.replace(":", "");
  // Use the last 10 characters of the MAC address for a shorter ID
  deviceID = mac.substring(mac.length() - 10);
  DBG_PRINT(F("[MAIN] Device ID (last 10 of MAC): "));
  DBG_PRINTLN(deviceID);

  // 2. Get GPS Data
  if (power_instruction_get() != PowerInstruction::TurnOff) {
    DBG_PRINTLN(F("[MAIN] --- Initializing External GPS ---"));
    gps_power_up();
    gps_init_serial();
    gps_get_fix(GPS_ACQUISITION_TIMEOUT_MS); // Button presses are handled by ISR now
    gps_close_serial(); // De-initialize serial pins before cutting power
    gps_power_down(); // Power down GPS immediately after fix attempt
    if (shutdown_is_requested()) {
      DBG_PRINTLN(F("[MAIN] Shutdown requested after GPS stage. Aborting work cycle."));
      return;
    }
  } else {
    gpsFixObtained = false;
  }

  bool statusAckQueued = false;

  // 3. Cache the data point if a fix was obtained
  if (gpsFixObtained) {
    JsonDocument jsonDoc;
    jsonDoc["device"] = deviceID;
    jsonDoc["name"] = deviceName;
    jsonDoc["latitude"] = gpsLat;
    jsonDoc["longitude"] = gpsLon;
    jsonDoc["speed"] = gpsSpd;
    jsonDoc["altitude"] = gpsAlt;
    jsonDoc["accuracy"] = gpsHdop;
    jsonDoc["satellites"] = gpsSats;
    if (gpsYear != 0) {
      char timestamp[25];
      sprintf(timestamp, "%04d-%02d-%02dT%02d:%02d:%02dZ", gpsYear, gpsMonth, gpsDay, gpsHour, gpsMinute, gpsSecond);
      jsonDoc["timestamp"] = timestamp;
    }
    if (power_status_report_pending()) {
      jsonDoc["power_status"] = power_status_to_string(power_status_get());
      statusAckQueued = true;
    }
    String jsonData;
    serializeJson(jsonDoc, jsonData);
    append_to_cache(jsonData);
    cycleCounter++;
    DBG_PRINTF("[MAIN] Cycle %d complete. Batch size will be determined by server.\n", cycleCounter);
  }

  bool statusReportPending = power_status_report_pending();
  size_t cachedRecordCount = fs_get_cache_record_count();

  if (!gpsFixObtained && statusReportPending) {
    JsonDocument statusDoc;
    statusDoc["device"] = deviceID;
    statusDoc["name"] = deviceName;
    statusDoc["latitude"] = gpsLat;
    statusDoc["longitude"] = gpsLon;
    statusDoc["speed"] = gpsSpd;
    statusDoc["altitude"] = gpsAlt;
    statusDoc["accuracy"] = gpsHdop;
    statusDoc["satellites"] = gpsSats;
    if (gpsYear != 0) {
      char timestamp[25];
      sprintf(timestamp, "%04d-%02d-%02dT%02d:%02d:%02dZ", gpsYear, gpsMonth, gpsDay, gpsHour, gpsMinute, gpsSecond);
      statusDoc["timestamp"] = timestamp;
    } else {
      statusDoc["timestamp"] = "2000-01-01T00:00:00Z";
    }
    statusDoc["power_status"] = power_status_to_string(power_status_get());
    String statusJson;
    serializeJson(statusDoc, statusJson);
    append_to_cache(statusJson);
    statusAckQueued = true;
    cachedRecordCount = fs_get_cache_record_count(); // Re-count after adding status
  }

  // 4. Perform handshake and optionally send data in a single modem session
  // Only initiate modem session if batch threshold is met OR there's an urgent power status report to send
  if (shutdown_is_requested()) {
    DBG_PRINTLN(F("[MAIN] Shutdown requested before modem session. Skipping network operations."));
  } else if (cachedRecordCount >= batchSizeThreshold || statusReportPending || power_instruction_get() == PowerInstruction::TurnOff) {
    DBG_PRINTLN(F("[MAIN] Starting modem session (handshake + optional upload)."));
    bool modemInitialized = false;
    bool gprsConnected = false;

    if (modem_initialize()) {
      modemInitialized = true;
      if (modem_connect_gprs(apn, gprsUser, gprsPass)) {
        gprsConnected = true;
        bool handshakeSuccess = modem_perform_handshake();
        if (!handshakeSuccess) {
          DBG_PRINTLN(F("[MAIN] Handshake did not complete successfully."));
        } else {
          // Handshake includes power_status, so we can consider the report sent.
          // This prevents a loop if the subsequent batch upload fails.
          if (power_status_report_pending()) {
            power_status_report_acknowledged();
            // Also acknowledge instruction if we just reported matching status
            if (power_instruction_get() == PowerInstruction::TurnOff && power_status_get() == PowerStatus::Off) {
                 power_instruction_acknowledged();
            }
          }
        }

        if (!isRegistered) {
          DBG_PRINTLN(F("[MAIN] Device reported as unregistered during handshake. Entering shutdown."));
          modem_disconnect_gprs();
          modem_power_off();
          graceful_shutdown();
          return;
        }

        if (power_status_report_pending() && !statusAckQueued) {
          JsonDocument statusDoc;
          statusDoc["device"] = deviceID;
          statusDoc["name"] = deviceName;
          statusDoc["latitude"] = gpsLat;
          statusDoc["longitude"] = gpsLon;
          statusDoc["speed"] = gpsSpd;
          statusDoc["altitude"] = gpsAlt;
          statusDoc["accuracy"] = gpsHdop;
          statusDoc["satellites"] = gpsSats;
          if (gpsYear != 0) {
            char timestamp[25];
            sprintf(timestamp, "%04d-%02d-%02dT%02d:%02d:%02dZ", gpsYear, gpsMonth, gpsDay, gpsHour, gpsMinute, gpsSecond);
            statusDoc["timestamp"] = timestamp;
          } else {
            statusDoc["timestamp"] = "2000-01-01T00:00:00Z";
          }
          statusDoc["power_status"] = power_status_to_string(power_status_get());
          String statusJson;
          serializeJson(statusDoc, statusJson);
          append_to_cache(statusJson);
          statusAckQueued = true;
        }

        bool hasDataToSend = fs_cache_exists();
        if (hasDataToSend) {
          DBG_PRINTLN(F("[MAIN] Data available for upload. Attempting to send."));
          if (send_cached_data()) {
            cycleCounter = 0;
          }
        } else {
          DBG_PRINTLN(F("[MAIN] No data pending after handshake."));
        }

        modem_disconnect_gprs();
        gprsConnected = false;
      } else {
        DBG_PRINTLN(F("[MAIN] Failed to connect to GPRS. Data remains cached."));
      }

      modem_power_off();
      modemInitialized = false;
    } else {
      DBG_PRINTLN(F("[MAIN] Failed to initialize modem for network session."));
    }

    if (gprsConnected) {
      modem_disconnect_gprs();
    }
    if (modemInitialized) {
      modem_power_off();
    }
  }

  if (power_instruction_should_shutdown()) {
    DBG_PRINTLN(F("[MAIN] Power instruction acknowledged. Shutting down device."));
    power_instruction_clear();
    graceful_shutdown();
    return;
  }

  // 5. Clean up file system resources
  if (!shutdown_is_requested()) {
    fs_end();
    DBG_PRINTLN(F("[MAIN] Work cycle finished."));
  } else {
    DBG_PRINTLN(F("[MAIN] Work cycle aborted due to shutdown request."));
  }
}

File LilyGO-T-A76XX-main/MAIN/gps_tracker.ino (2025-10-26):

// Include necessary libraries
#include "utilities.h"       // For board-specific definitions (copy this file to the MAIN/ directory)
#include <TinyGsmClient.h>
#include <ArduinoJson.h>     // For creating JSON payloads
#include "esp_sleep.h"       // For deep sleep functionality
#include <TinyGPS++.h>       // For external GPS module
#include <SoftwareSerial.h>  // For external GPS module communication

// --- OTA Includes ---
#include <WiFi.h>
#include <WebServer.h>
#include <Update.h>
#include <LittleFS.h>
#include <Preferences.h>

// --------------------------- Configuration ---------------------------------
// --- Modem Configuration (A7670E) ---
#define SerialMon Serial
// #define TINY_GSM_DEBUG SerialMon // Uncomment for TinyGSM internal debug
// #define DUMP_AT_COMMANDS // Uncomment to see all AT commands

// --- External GPS Module Configuration ---
#define GPS_RX_PIN    32  // ESP32 RX <- GPS TX
#define GPS_TX_PIN    33  // ESP32 TX -> GPS RX
#define GPS_POWER_PIN 5   // ESP32 pin to control power to GPS module (via transistor)
#define GPS_BAUD_RATE 9600
#define SAT_THRESHOLD 1   // Minimum satellites for a valid fix
int minSatellitesForFix = SAT_THRESHOLD;
// --- GPRS Configuration ---
// Default values. These will be overwritten by values from Preferences if they exist.
String apn      = "internet.t-mobile.cz";
String gprsUser = "gprs";
String gprsPass = "gprs";

// --- Server Configuration ---
String server  = "lotr-system.xyz";
int    port      = 443;
const char resourcePost[] = "/api/devices/input";

#define CACHE_FILE "/gps_cache.log"
#define PREFERENCES_NAMESPACE "gps-tracker"
#define KEY_BATCH_SIZE "batch_size"

// --- Device & GPS Configuration ---
String deviceName = "NEO-6M_A7670E";
const char* deviceID = ""; // Device ID for the payload
const unsigned long GPS_ACQUISITION_TIMEOUT_MS = 5 * 60 * 1000; // 5 minutes for GPS fix attempt

// --- Sleep Configuration ---
const uint64_t DEFAULT_SLEEP_SECONDS = 60;
uint64_t sleepTimeSeconds = DEFAULT_SLEEP_SECONDS;

// --- OTA Configuration ---
const int otaPin = 23; // GPIO pin for OTA mode switch (connect to 3.3V for OTA mode)
// Default OTA SSID will be finalized after DeviceID is known in setup()
String ota_ssid = "lotrTrackerOTA";
String ota_password = "password";

WebServer otaServer(80);

Preferences preferences;
RTC_DATA_ATTR int cycleCounter = 0; // Counts boot cycles, survives deep sleep

// HTML for OTA upload page
const char* update_form_page = R"rawliteral(
  <html>
  <head>
    <title>OTA Update</title>
    <meta name="viewport" content="width=device-width, initial-scale=1.0">
    <style>
      body { font-family: Arial, sans-serif; margin: 0; padding: 20px; background-color: #f4f4f4; display: flex; justify-content: center; align-items: center; min-height: 90vh; text-align: center; }
      .container { background-color: #fff; padding: 30px; border-radius: 8px; box-shadow: 0 0 10px rgba(0,0,0,0.1); max-width: 400px; width: 100%; }
      h1 { color: #333; }
      p { color: #555; line-height: 1.5; }
      .status { padding: 10px; border-radius: 4px; margin: 15px 0; font-weight: bold; }
      .status.ok { background-color: #d4edda; color: #155724; }
      .status.fail { background-color: #f8d7da; color: #721c24; }
      .form-group { margin-bottom: 15px; text-align: left; }
      label { display: block; margin-bottom: 5px; font-weight: bold; }
      input[type='text'], input[type='password'], input[type='file'] { width: calc(100% - 22px); padding: 10px; border: 1px solid #ddd; border-radius: 4px; } /* Added input[type='file'] */
      input[type='submit'] { background-color: #28a745; color: white; padding: 10px 20px; border: none; border-radius: 4px; cursor: pointer; font-size: 1em; width: 100%; } /* Changed color to green */
      input[type='submit']:hover { background-color: #218838; } /* Changed hover color */
      .nav-menu { margin-top: 20px; padding-top: 10px; border-top: 1px solid #eee; }
      .nav-menu a { margin: 0 10px; color: #007bff; text-decoration: none; }
      .nav-menu a:hover { text-decoration: underline; }
    </style>
  </head>
  <body>
    <div class="container">
      <h1> GPSTracker Update</h1>
      <p><b>Device ID:</b> %id%</p>
      <p>Connect to Wi-Fi: <b>%s</b></p>
      <form method='POST' action='/update' enctype='multipart/form-data'>
        <input type='file' name='update' accept='.bin' required><br>
        <input type='submit' value='Upload and Update'>
      </form>
      <div class="nav-menu">
        <a href="/">Main Page</a> | 
        <a href="/settings">Settings</a>
      </div>
    </div>
  </body>
  </html>
)rawliteral";

// HTML for success page
String success_page = R"rawliteral(
  <html><head><title>OTA Update Success</title>
  <style>body{font-family: Arial, sans-serif; text-align: center; padding-top: 50px;} .message{color: green; font-size: 1.2em;}</style></head>
  <body>
    <h1>OTA Update Successful!</h1>
    <p class="message">Firmware has been updated.<br>Please manually power cycle the device and switch to ON mode.</p>
    <p><a href="/">Upload another file</a></p>
  </body></html>
)rawliteral";

// HTML for failure page template
String failure_page_template = R"rawliteral(
  <html><head><title>OTA Update Failed</title>
  <style>body{font-family: Arial, sans-serif; text-align: center; padding-top: 50px;} .message{color: red; font-size: 1.2em;}</style></head>
  <body>
    <h1>OTA Update Failed!</h1>
    <p class="message">Error: %s</p>
    <p><a href="/">Try again</a></p>
  </body></html>
)rawliteral";

// --- HTML for OTA Response Page ---
const char* ota_response_page_template = R"rawliteral(
  <html>
  <head>
    <title>Registration Status</title>
    <meta name="viewport" content="width=device-width, initial-scale=1.0">
    <style>
      body { font-family: Arial, sans-serif; margin: 0; padding: 20px; background-color: #f4f4f4; display: flex; justify-content: center; align-items: center; min-height: 90vh; text-align: center; }
      .container { background-color: #fff; padding: 30px; border-radius: 8px; box-shadow: 0 0 10px rgba(0,0,0,0.1); max-width: 400px; width: 100%; }
      h1 { color: #333; }
      p { color: #555; line-height: 1.5; }
      .status-message { padding: 10px; border-radius: 4px; margin: 20px 0; font-weight: bold; font-size: 1.1em; }
      .status-message.ok { background-color: #d4edda; color: #155724; }
      .status-message.fail { background-color: #f8d7da; color: #721c24; }
      a { color: #007bff; text-decoration: none; margin-top: 15px; display: inline-block; }
      a:hover { text-decoration: underline; }
    </style>
  </head>
  <body>
    <div class="container">
      <h1>Registration Status</h1>
      <div class="status-message %status_class%">%message%</div>
      <a href="/">Go Back</a>
    </div>
  </body>
  </html>
)rawliteral";
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

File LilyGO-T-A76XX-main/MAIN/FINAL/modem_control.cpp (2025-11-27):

#include "modem_control.h"
#include <ArduinoJson.h>
#include <TinyGsmClient.h>
#include "freertos/FreeRTOS.h"
#include "freertos/semphr.h"
#include "power_management.h"
#include "file_system.h"

// Global modem objects
#ifdef DUMP_AT_COMMANDS
#include <StreamDebugger.h>
StreamDebugger debugger(SerialAT, SerialMon);
TinyGsm g_modem(debugger);
#else
TinyGsm g_modem(SerialAT);
#endif
TinyGsmClient g_client(g_modem);

namespace {
portMUX_TYPE g_modem_mutex_init_mux = portMUX_INITIALIZER_UNLOCKED;
SemaphoreHandle_t g_modem_mutex = nullptr;
bool g_modem_initialized = false;
bool g_modem_gprs_connected = false;

inline void mark_modem_offline() {
  g_modem_initialized = false;
  g_modem_gprs_connected = false;
}

SemaphoreHandle_t get_modem_mutex() {
  if (g_modem_mutex == nullptr) {
    portENTER_CRITICAL(&g_modem_mutex_init_mux);
    if (g_modem_mutex == nullptr) {
      g_modem_mutex = xSemaphoreCreateRecursiveMutex();
    }
    portEXIT_CRITICAL(&g_modem_mutex_init_mux);
  }
  return g_modem_mutex;
}

class ModemLockGuard {
 public:
  explicit ModemLockGuard(TickType_t timeout = portMAX_DELAY) {
    mutex_ = get_modem_mutex();
    locked_ = (mutex_ != nullptr) && (xSemaphoreTakeRecursive(mutex_, timeout) == pdTRUE);
  }

  ~ModemLockGuard() {
    if (locked_) {
      xSemaphoreGiveRecursive(mutex_);
    }
  }

  bool isLocked() const { return locked_; }

 private:
  SemaphoreHandle_t mutex_ = nullptr;
  bool locked_ = false;
};
} // namespace

// Global variables (declared extern in modem_control.h and other modules)
extern String apn;
extern String gprsUser;
extern String gprsPass;
extern String server;
extern int port;
extern String deviceID;
extern String deviceName;
extern bool isRegistered;
extern uint64_t sleepTimeSeconds;
extern int minSatellitesForFix;

bool modem_initialize() {
  ModemLockGuard lock;
  if (!lock.isLocked()) {
    DBG_PRINTLN(F("[MODEM] Unable to acquire modem lock for initialization."));
    return false;
  }
  if (shutdown_is_requested()) {
    DBG_PRINTLN(F("[MODEM] Initialization skipped due to shutdown request."));
    return false;
  }
  if (g_modem_initialized) {
    DBG_PRINTLN(F("[MODEM] Modem already initialized."));
    return true;
  }
  DBG_PRINTLN(F("[MODEM] Initializing modem..."));

#ifdef BOARD_POWERON_PIN
  pinMode(BOARD_POWERON_PIN, OUTPUT);
  digitalWrite(BOARD_POWERON_PIN, HIGH);
#endif

  // Helper lambda to toggle PWRKEY
  auto togglePwrKey = []() {
    DBG_PRINTLN(F("[MODEM] Toggling PWRKEY..."));
    pinMode(BOARD_PWRKEY_PIN, OUTPUT);
    digitalWrite(BOARD_PWRKEY_PIN, LOW);
    delay(100);
    digitalWrite(BOARD_PWRKEY_PIN, HIGH);
    delay(1000);
    digitalWrite(BOARD_PWRKEY_PIN, LOW);
    DBG_PRINTLN(F("[MODEM] PWRKEY toggled. Waiting for boot..."));
  };

  // Helper to wait for AT response (Adaptive Wait)
  auto waitForModemToBoot = [](uint32_t timeout_ms) -> bool {
      unsigned long start = millis();
      while (millis() - start < timeout_ms) {
          if (g_modem.testAT(100)) { // Fast check
              return true;
          }
          delay(100); // Small delay between attempts
          if (shutdown_is_requested()) return false;
      }
      return false;
  };

  // Initialize SerialAT immediately
  SerialAT.begin(115200, SERIAL_8N1, MODEM_RX_PIN, MODEM_TX_PIN);
  delay(100);

  bool modemReady = false;

  // Check 1: Already ON? (Quick check)
  if (g_modem.testAT(500)) {
      DBG_PRINTLN(F("[MODEM] Modem responded to AT. It is already ON."));
      modemReady = true;
  } else {
      DBG_PRINTLN(F("[MODEM] No response. Performing Power-On sequence (Attempt 1)..."));
      
      #ifdef MODEM_RESET_PIN
      DBG_PRINTLN(F("[MODEM] Resetting modem..."));
      pinMode(MODEM_RESET_PIN, OUTPUT);
      digitalWrite(MODEM_RESET_PIN, !MODEM_RESET_LEVEL);
      delay(100);
      digitalWrite(MODEM_RESET_PIN, MODEM_RESET_LEVEL);
      delay(2600);
      digitalWrite(MODEM_RESET_PIN, !MODEM_RESET_LEVEL);
      delay(500);
      #endif

      togglePwrKey();
      
      // Adaptive wait for boot (up to 10 seconds)
      if (waitForModemToBoot(10000)) {
          modemReady = true;
      } else {
          // Re-init serial just in case
          SerialAT.begin(115200, SERIAL_8N1, MODEM_RX_PIN, MODEM_TX_PIN);
          delay(500);

          DBG_PRINTLN(F("\n[MODEM] Still no response. We might have turned it OFF. Toggling PWRKEY again (Attempt 2)..."));
          togglePwrKey();
          
          // Adaptive wait for boot (up to 10 seconds)
          if (waitForModemToBoot(10000)) {
             modemReady = true;
          }
      }
  }

  if (!modemReady) {
      DBG_PRINTLN(F("\n[MODEM] Failed to power on modem after two attempts."));
      mark_modem_offline();
      return false;
  }

  DBG_PRINTLN(F("\n[MODEM] AT command responded."));

  DBG_PRINTLN(F("[MODEM] Initializing modem with modem.init()..."));
  if (!g_modem.init()) {
    DBG_PRINTLN(F("[MODEM] Modem init failed. Trying restart..."));
    delay(1000);
    if (!g_modem.restart()) {
      DBG_PRINTLN(F("[MODEM] Modem restart also failed!"));
      mark_modem_offline();
      return false;
    }
    DBG_PRINTLN(F("[MODEM] Modem restart successful."));
  } else {
    DBG_PRINTLN(F("[MODEM] Modem init successful."));
  }

  String modemInfo = g_modem.getModemInfo();
  DBG_PRINT(F("[MODEM] Modem Info: "));
  DBG_PRINTLN(modemInfo);
  if (modemInfo.indexOf("A76") == -1) {
    DBG_PRINTLN(F("[MODEM] Warning: Modem info does not look like A76XX series."));
  }
  g_modem_initialized = true;
  return true;
}

bool modem_connect_gprs(const String& apn_val, const String& user_val, const String& pass_val, uint32_t timeout_ms) {
  ModemLockGuard lock;
  if (!lock.isLocked()) {
    DBG_PRINTLN(F("[MODEM] Unable to acquire modem lock for GPRS connect."));
    return false;
  }
  if (shutdown_is_requested()) {
    DBG_PRINTLN(F("[MODEM] GPRS connect skipped due to shutdown request."));
    return false;
  }
  if (!g_modem_initialized) {
    DBG_PRINTLN(F("[MODEM] Cannot connect GPRS: modem not initialized."));
    return false;
  }
  DBG_PRINT(F("[MODEM] Waiting for network..."));
  if (!g_modem.waitForNetwork(timeout_ms, true)) {
    DBG_PRINTLN(F(" fail"));
    g_modem_gprs_connected = false;
    return false;
  }
  DBG_PRINTLN(F(" success"));

  DBG_PRINT(F("[MODEM] Connecting to GPRS: "));
  DBG_PRINT(apn_val);
  if (!g_modem.gprsConnect(apn_val.c_str(), user_val.c_str(), pass_val.c_str())) {
    DBG_PRINTLN(F(" fail"));
    g_modem_gprs_connected = false;
    return false;
  }
  DBG_PRINTLN(F(" success"));
  DBG_PRINT(F("[MODEM] GPRS IP: "));
  DBG_PRINTLN(g_modem.getLocalIP());
  g_modem_gprs_connected = true;
  return true;
}
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

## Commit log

2025-07-09 multi_user web + DB administration + device Registration
2025-07-09 DeviceID generation - HW
2025-09-28 apk28.9 ON/OFF -> fixed
    [gps_tracker.ino]
2025-09-29 night/day prototype
2025-10-03 clustering_map data
    [víko - kopie.0004.ipt, víko - kopie.ipt]
2025-11-07 HWcomm[DONE?] , ServerAPI[DONE?], APK[NOT YET!] --2requestcomm --powermodul
2025-11-17 apk-logger?,apk-recting-tunoffflag, server-alerts-logic(withoutreason),cable-managment
2025-11-21 data_config, reset and cache_clearing-possible_in_OTA
    [main.ino]
